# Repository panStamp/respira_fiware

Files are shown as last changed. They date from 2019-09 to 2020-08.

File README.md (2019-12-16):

# Open FIWARE air monitoring platform for urban applications

RESPIRA FIWARE is an open source air monitoring device created to sense temperature, humidity, particle matter and NO2 levels in the air. This device transmits levels and concentrations to a central FIWARE platform and has been originally created to connect and transmit against the RESPIRA Environmental IoT platform of Badajoz. Both projects have been developped by [panStamp](http://www.panstamp.com) and sponsored by [Diputación de Badajoz](https://www.dip-badajoz.es/) and [Telefónica](https://www.telefonica.com/en/)

# Index of contents

- [Introduction](docs/en/INTRODUCTION.md)
- [RESPIRA station](docs/en/RESPIRA_STATION.md)
  - [How to build RESPIRA station](docs/en/HOWTO_BUILD_STATION.md)
  - [Maintenance and calibration of RESPIRA stations](docs/en/RESPIRA_CALIBRATION.md)
  - [RESPIRA calibration tool](docs/en/RESPIRA_TOOL.md)
- [RESPIRA environmental IoT platform](docs/en/RESPIRA_PLATFORM.md)
  - [How to use the RESPIRA IoT platform](docs/en/HOWTO_RESPIRA_PLATFORM.md)
  - [Alert panel](docs/en/ALERT_PANEL.md)
  - [HTTP API](docs/en/API_DOC.md)

# Source code and documentation

The source code of the RESPIRA station and all the necessary documentation for the building and start up processes are available on [Github](https://github.com/panStamp/respira_fiware).

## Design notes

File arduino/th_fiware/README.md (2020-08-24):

# Basic FIWARE temperature and humidity sensor

This is a basic example showing how to connect a temperature and humidity sensor to our RESPIRA open platform via FIWARE UltraLight. The source code is ready to upload to a ESP8266 SoC from an Arduino IDE. The sensor is a SI7021 dual temperature and humidity sensor supporting I2C communications.

## Necessary steps before compiling:

1. Install ESP8266 Arduino cores from the Arduino boards manager by following this guide: 
https://github.com/esp8266/Arduino#installing-with-boards-manager

2. Install SparkFun's SI7021 library from the Arduino library manager:
https://github.com/sparkfun/SparkFun_Si701_Breakout_Arduino_Library

3. Install WiFi Manager by tzapu also from the Arduino library manager:
https://github.com/tzapu/WiFiManager#install-through-library-manager

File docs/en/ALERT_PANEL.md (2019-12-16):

[< back to index](../../README.md)

# Alert panel

The alert panel provides a simple way to define and track alerts based on any public IoT value published by the RESPIRA platform. Only registered users can create alerts and visualize them from their accounts.

## Alert creation

Alerts can be created from _Alerts->Manager alerts_ and then press on _Add new alert_. The following form will open:

<p align="center">
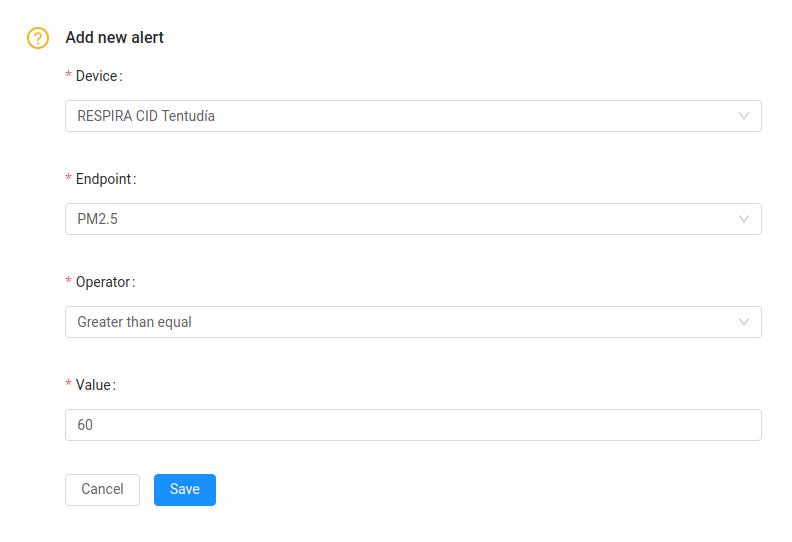
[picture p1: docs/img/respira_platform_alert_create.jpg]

</p>

This form is quite self-explanatory but the idea is to set the reading of a given device to trigger the alert whenever its value  is greater or lower (operator field) than a threshold (value field). Alerts are continuously checked and reported in the _Alert console_:

<p align="center">
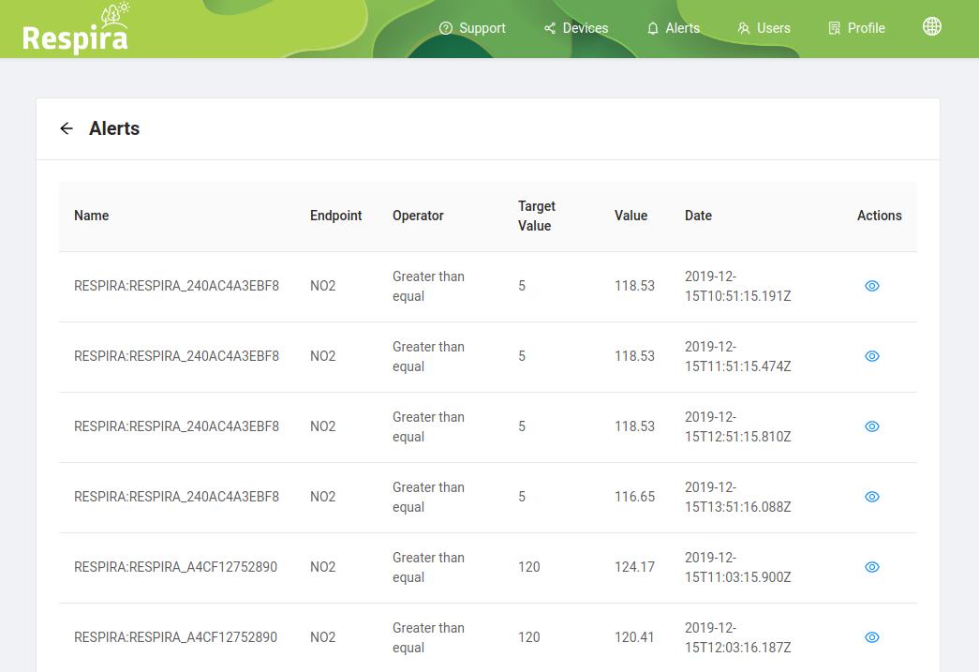
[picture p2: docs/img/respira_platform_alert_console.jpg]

</p>

At this point, the only way to navigate from the alert console to the specific device in the dashboard is to copy the id of the device from the alert console and then go to the dashboard.

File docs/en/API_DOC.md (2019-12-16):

[< back to index](../../README.md)

# HTTP API

The HTTP API provides a way for programmers and specialists to download data from specific devices in a time range. An example of this API is provided for every device on the side panel:

<p align="center">
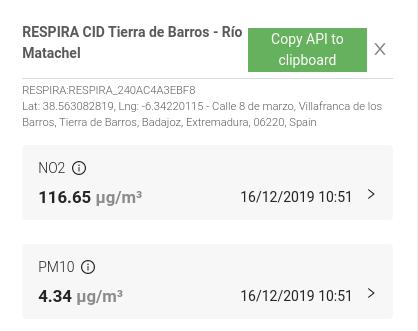
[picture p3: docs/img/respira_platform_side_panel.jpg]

</p>

Clicking on _Copy API to clipboard_ on the above panel provides the following HTTP call:

```
http://calidadmedioambiental.org/api/v1/data/RESPIRA:RESPIRA_240AC4A3EBF8/2019-12-15T10:03:41/2019-12-16T10:03:41/json
```

Then it's simply a matter of modifying the call for our date and time range. Data can be downloaded in json and csv format, according to the API format:

```
http://calidadmedioambiental.org/api/v1/data/<Device profile>:<Device id>/<initial time>/<final time>/<format>
```

Being <format> either _json_ or _csv_

Time strings need to conform to the standard format: yyyy-mm-ddTHH:MM:SS

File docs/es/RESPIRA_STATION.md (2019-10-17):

[< índice](INDEX.md)

# Índice de contenidos

- [La estación RESPIRA FIWARE](#la-estación-RESPIRA-FIWARE)
- [Especificaciones](#especificaciones)
- [Funcionamiento](#funcionamiento)
- [Componentes](#componentes)
  - [Microcontrolador](#microcontrolador)
  - [Sensores](#sensores)

# La estación RESPIRA FIWARE

La arquitectura del hardware RESPIRA es bastante sencilla. Un módulo ESP32 actúa como el cerebro de la estación medioambiental. Por otra parte, la lectura de temperatura ambiente, humedad relativa y concentraciones de NO2 y de partículas (PM) es proporcionada desde tres sensores independientes vía I2C y UART. El SoC ESP32 tiene suficiente espacio en flash y potencia para almacenar y procesar las lecturas internamente con el fin de limpiar y filtrar los datos y de ejecutar rutinas de calibración periódicas. Por último, la información procesada es transmitida a la plataforma FIWARE por medio de una [petición HTTP UltraLight 2.0](https://fiware-iotagent-ul.readthedocs.io/en/latest/usermanual/index.html).

# Especificaciones

- Parámetros proporcionados: Temperatura ambiente, humidity relativa, NO2, PM1.0, PM2.5, PM4.0, PM10, tamaño típico de partículas y [CAQI](https://en.wikipedia.org/wiki/Air_quality_index#CAQI)
- Alimentación : 5.0VDC
- Corriente máxima : 300 mA
- Comunicación : WiFi 2.4GHz
- Protocolo FIWARE: UltraLight 2.0 HTTP

# Funcionamiento

Toda estación RESPIRA recoge datos medioambientales cada 20 segundos. Estos datos son almacenados para realizar una media aritmética cada hora e inmediatamente transmitir estas medias hacia la plataforma. Las estaciones RESPIRA transmiten pues valores medios cada hora.

Por otra parte, las estaciones RESPIRA también realizan compensaciones internas de las lecturas en temperatura y también otras rutinas de compensación explicadas [aquí](RESPIRA_CALIBRATION.md).

<p align="center">
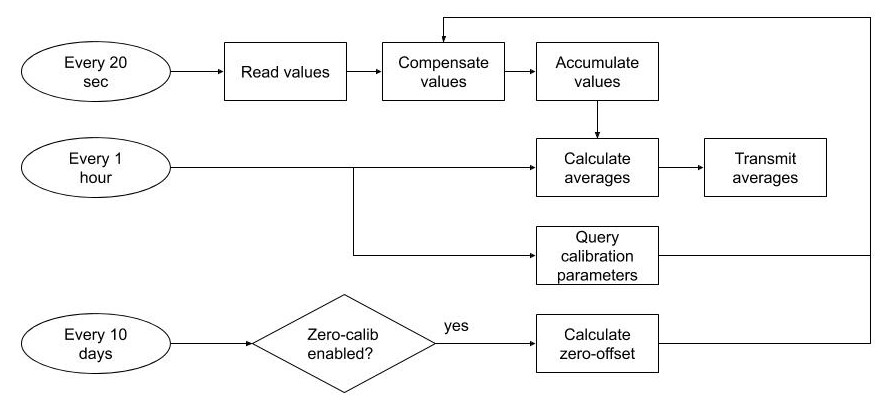
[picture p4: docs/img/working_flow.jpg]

</p>

# Componentes

RESPIRA FIWARE está formado por dos partes principales. La primera parte es la unidad microcontrolada, el cerebro de la solución que contiene el módulo ESP32 con las comunicaciones WiFi. La segunda parte es el bloque de sensorización, contenido dentro de un encapsulado con formato pagoda que garantiza la ventilación. Ambas partes comunican entre sí por medio de I2C y UART.

## Microcontrolador

Esta tarjeta usa exclusivamente componentes "con patas" (THT) con el fin de facilitar su montaje y de permitir su prototipado desde la comunidad. Es por esto que hemos escogido un módulo ESP32 en formato NodeMCU. Este módulo no sólo contiene un SoC (System On Chip) ESP32  sino que además incluye un interfaz USB, usado para programar y depurar el firmware, y de un regulador de tensión de 3.3VDC. La tarjeta NodeMCU ESP32 también incluye un par de botones que permiten poner el ESP32 en modo programación de forma manual.

<p align="center">

</p>

La tarjeta microcontrolada se ajusta a la parte izquierda de una caja FIBOX TEMPO TAM131007 para exteriores, dejando toda la parte derecha del interior de la caja para el montaje de futura sensorización así como de una fuente de alimentación de 5 VDC.

## Sensores

Los sensores quedan ensamblados en el interior de una cápsula preparada para la sensorización del aire y que facilita su ventilación de forma pasiva. Hemos elegido para este poroyecto la caja con referencia TFA-Dostmann 98.1114.02, normalmente disponible en Amazon.

RESPIRA se apoya en tres sensores externos, los cuales han sido elegidos por su respuesta, estabilidad y capacidad para comunicar de forma digital con el microcontrolador.

### Sensor de temperatura y humedad [SI7021](https://www.silabs.com/documents/public/data-sheets/Si7021-A20.pdf)

Este integrado fabricado por Silicon Labs es un sensor dual de temperatura y humedad excepcional que comunica por I2C. Existe multitud de librerías para Arduino compatibles con este sensor y también está disponible en formato de tarjeta de prototipaje, de forma que se evita el montaje superficial. Estas tarjetas con sensor SI7021 están disponibles en eBay o Aliexpress por menos de 4 EUR.

<p align="center">

</p>

### Sensor de partículas [SPS30](https://www.sensirion.com/en/environmental-sensors/particulate-matter-sensors-pm25/)

SPS30 es un sensor compacto de partículas fabricado por Sensirion. Este sensor es capaz de detectar partículas con diámetros desde 0.5 micras, calcular concentraciones para cada diámetro y también calcular la masa total por diámetro. El dispositivo SPS30 tiene dimensiones reducidas (41x41x12 mm) y dispone de conectividad por UART y por I2C. SPS30 está disponible en Mouser y en Digikey a precios que rondan los 40 EUR en pequeñas cantidades.

<p align="center">

</p>

SPS30 proporciona los siguientes parámetros:

- Concentración de PM1.0, PM2.5, PM4.0 y PM10
- Tamaño medio de las partículas detectadas

### Sensor de NO2 [ES1-NO2-50](http://pmo0ec072.pic33.websiteonline.cn/upload/ES1-NO2-50_20171212.pdf)

ES1-NO2-50 es un sensor electroquímico de NO2 sensor sensible en el rango de 0 a 50 ppm. Por supuesto, no necesitamos todo ese rango de lecturas aunque este sensor se comporta especialmente bien ante concentraciones bajas de NO2. Por otra parte, la deriva del sensor es mínima en rangos bajos de lectura y viene calibrado de fábrica. Con el fin de simplificar todavía más la integración de este sensor en nuestra estación RESPIRA, el sensor viene montado sobre una tarjeta TB600, también del mismo fabricante, que proporciona comunicación por puerto serie UART. De esta forma evitamos tener que lidiar con lecturas analógicas complicadas desde el ESP32.

<p align="center">

</p>

ES1-NO2-50 y TB600 es fabricado por ECSense y distribuído en Europa por Pewatron. Su precio ronda los 120 EUR en pequeñas cantidades.

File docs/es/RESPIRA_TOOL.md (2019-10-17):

[< índice](INDEX.md)

# Índice de contenidos

- [RESPIRA tool](#respira-tool)
- [Configuración inicial](#configuración-inicial)
- [Corrección manual por factor-offset](#corrección-manual-por-factor-offset)
- [Corrección automática por nivel cero](#corrección-automática-por-nivel-cero)
- [Reset de los parámetros de calibración](#reset-de-los-parámetros-de-calibración)
- [Lectura de los parámetros de calibración](#lectura-de-los-parámetros-de-calibración)

# RESPIRA tool

RESPIRA tool es un programa en línea de comandos (terminal) desarrollado en Python 3.7 para enviar configuración y parámetros de calibración a cualquier estación remota RESPIRA por medio de FIWARE. Ya explicamos en [esta otra sección](RESPIRA_CALIBRATION.md) dos estrategias distintas de calibración: corrección manual por factor-offset y calibración automática por nivel cero. Los siguientes apartados emplean cada uno de estos métodos por medio del correspondiente comando.

# Configuración inicial

Antes de usar RESPIRA tool necesitamos introducir nuestro service path FIWARE. A todo usuario de la plataforma RESPIRA IoT medioambiental se el proporciona un service path, una región específica dentro del Context-Broker FIWARE donde confluyen todas la sinformaciones IoT. Los usuarios pueden encontrar su service path bajo su perfil en la plataforma.

Con el service path en mano, basta con ejecutar el siguiente comando:

```
python3 respira_tool.py --set-service-path /my_service_path
```

Este comando almacena el service path en un fichero de configuración, de modo que no necesitaremos volver a ejecutar el comando salvo que que queramos cambiar a un service path distinto (distinto usuario). Podemos comprobar el service path vigente en todo momento mediante este otro comando:

```
python3 respira_tool.py --show-service-path
```

devolviendo el service path actualmente en curso:

```
/my_service_path
```

# Corrección manual por factor-offset

Asumiendo que ya se dispone de los parámetros de corrección (factor y offset), su transmisión a FIWARE sólo requiere de la ejecución de este comando:

```
python3 respira_tool.py --calibrate no2 -d RESPIRA_XXXXXXXXXXXX -f 1.0021 -o -12.687
```

Donde no2 es la lectura que deseamos corregir, RESPIRA_XXXXXXXXXXXX es el ID de la estación RESPIRA, 1.0021 el factor de corrección (o ganancia) y -12.687 es el offset de corrección. Los contaminantes soportados por esta versión del software son: no2, pm1.0, pm2.5, pm4.0 y pm10, de forma que podemso enviar calibraciones individuales para cada uno de los gases y diámetros de partículas.

```
python3 respira_tool.py --calibrate pm2.5 -d RESPIRA_XXXXXXXXXXXX -f 1.0016 -o 5.342
```

Las estaciones RESPIRA consultan el Context-Broker FIWARE de forma periódica cada hora con el fin de obtener los parámetros de configuración. Una vez obtenidos estos parámetros, la estación empieza a aplicar las correcciones sobre las siguientes lecturas, de forma que las correcciones se hacen visibles tras la siguiente transmisión una hora más tarde.

# Corrección automática por nivel cero

Esta estrategia permite a la estación restar un offset de nivel cero a cada lectura. Este nivel cero corresponde al valor mínimo detectado en el intervalo de los últimos 10 días. Podemos habilitar esta funcionalidad tanto para el sensor de NO2 como de partículas (SPS30). Es necesario reseñar que no es posible activar este tipo de compensación únicamente para un tipo de partícula sino que hay que hacerlo para todos los diámetros a los que el dispositivo SPS30 es sensible.

Estos comandos habilitan la calibración automática por nivel cero para cada sensor:

```
python3 respira_tool.py --enable-zero-calibration no2 -d RESPIRA_XXXXXXXXXXXX
python3 respira_tool.py --enable-zero-calibration pm -d RESPIRA_XXXXXXXXXXXX
```

y lo mismo para deshabilitar la funcionalidad:

```
python3 respira_tool.py --disable-zero-calibration no2 -d RESPIRA_XXXXXXXXXXXX
python3 respira_tool.py --disable-zero-calibration pm -d RESPIRA_XXXXXXXXXXXX
```

Tal y como se indica anteriormente, estos cambios surgen efecto a partir de la siguiente transmisión, una hora más tarde.

# Reset calibration settings

Digamos que queremos volver a los parámetros de configuración por defecto:

- Calibración automática por nivel cero deshabilitada para todos los sensores.
- Factor de corrección = 1 y offset = 0 para todos los contaminantes.

Podemos ejecutar este comando para volver a los valores por defecto:

```
python3 respira_tool.py --reset-calibration -d RESPIRA_XXXXXXXXXXXX
```

# Lectura de los parámetros de calibración

La opción _--read-calibration_ permite mostrarlos valores actuales de calibración de cualquier estación RESPIRA:

```
python3 respira_tool.py --read-calibration -d RESPIRA_XXXXXXXXXXXX
```

Respuesta de FIWARE:

```
Calibration settings for device :RESPIRA:RESPIRA_807D3AF39E18
NO2 automatic zero-calibration: enabled
NO2 correction factor (gain): 1
NO2 correction offset: 0
PM sensor automatic zero-calibration: enabled
PM1.0 correction factor (gain): 1
PM1.0 correction offset: 0
PM2.5 correction factor (gain): 1
PM2.5 correction offset: 0
PM4.0 correction factor (gain): 1
PM4.0 correction offset: 0
PM10 correction factor (gain): 1
PM10 correction offset: 0
```

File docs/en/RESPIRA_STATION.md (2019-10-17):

[< back to index](../../README.md)

# Index of contents

- [The RESPIRA FIWARE station](#the-respira-fiware-station)
- [Specifications](#specifications)
- [Working flow](#working-flow)
- [Components](#components)
  - [Microcontroller unit](#microcontroller-unit)
  - [Sensors](#sensors)

# The RESPIRA FIWARE station

The RESPIRA hardware follows a simple architecture. An ESP32 SoC acts as the brain of the environmental station. Ambient temperature, relative humidity, NO2 concentration and particle matter (PM) are read from three external sensors via I2C and UART. The ESP32 has sufficient space in flash and horsepower to internally store and process readings in order to filter levels and periodically run some calibration routines. Finally, processed information is transmitted to the FIWARE platform via a [HTTP UltraLight 2.0 request](https://fiware-iotagent-ul.readthedocs.io/en/latest/usermanual/index.html).

# Specifications

- Parameters provided: Temperature, humidity, NO2, PM1.0, PM2.5, PM4.0, PM10, typical particulate size and [CAQI](https://en.wikipedia.org/wiki/Air_quality_index#CAQI)
- Power supply : 5.0VDC
- Maximum current consummed : 300 mA
- Communication : WiFi 2.4GHz
- FIWARE protocol: UltraLight 2.0 HTTP

# Working flow

RESPIRA stations read environmental values every 20 seconds. This information is stored in order to get the arithmetic mean every hour and then transmit averages to the IoT platform. RESPIRA stations transmit then average values every hour.

On the other hand, RESPIRA stations also run some internal compensation algorithms based on temperature and some other calibration methods explained [here](RESPIRA_CALIBRATION.md).

<p align="center">

</p>

# Components

RESPIRA FIWARE is formed by two main blocks. The first block is the microcontroller unit, the core of the solution containing the ESP32 board and and the necessary connectivity. The second block is the sensing element, a pagoda-style enclosure containing the environmental sensors. Both main components communicate between them via UART and I2C.

## Microcontroller unit

This board relies only on "through-hole" (THT) components in order to simplify the assembly and let the community build RESPIRA stations on basic prototyping boards. As result, we have then chosen an ESP32 NodeMCU board as the ESP32 core. This board not only contains an ESP32 SoC but also a USB interface, used to program and debug the SoC, an on-board 3.3 VDC PSU and a couple of push buttons to manually put the board in programming mode.

<p align="center">

</p>

The microcontroller board fits into a FIBOX TEMPO TAM131007 box on the left side whilst keeping the right side of the enclosure free in case the user decides to add connectivity for some additional sensors or even place a 5VDC power supply.

## Sensors

Sensors are assembled into a pagoda-style enclosure in order to achive the best passive ventilation. We have chosen for this project the TFA-Dostmann 98.1114.02 enclosure, usually available on Amazon.

RESPIRA relies on three external sensors, which have been retained for their accuracy, stability and communication capabilities.

### [SI7021](https://www.silabs.com/documents/public/data-sheets/Si7021-A20.pdf) Temperature and Humidity sensor

This IC made by Silicon Labs is an exceptional dual temperature-humidity sensor that can be operated via I2C. There are lots of Arduino libraries for this sensor and is also available in form of breakout board so that there is no need to do any surface soldering. These boards are available on eBay and Aliexpress for less than 4 EUR.

<p align="center">

</p>

### [SPS30](https://www.sensirion.com/en/environmental-sensors/particulate-matter-sensors-pm25/) Particulate Matter sensor

SPS30 is an advanced compact particulate matter sensor designed and manufactured by Sensirion. It is capable to detect particles from 0.5 to 10 microns, calculate concentration for each diameter and even calculate the total mass per diameter. SPS30 features a small package (41x41x12mm) and provides connectivity via UART and I2C. SPS30 is available on Mouser and Digikey for around 40 EUR in small quantities.

<p align="center">

</p>

The following parameters are obtained from the SPS30 sensor:

- Concentration of PM1.0, PM2.5, PM4.0 and PM10
- Total average size of particules detected

### [ES1-NO2-50](http://pmo0ec072.pic33.websiteonline.cn/upload/ES1-NO2-50_20171212.pdf) NO2 sensor

ES1-NO2-50 is an electrochemical NO2 sensor sensible in the 0 to 50 ppm range. Of course we dont need that full range but the sensor performs quite well in low concentrations of gas. Moreover, the zero drift is minimum and the sensor comes calibrated from factory. In order to simplify the integration of this tiny sensor, it can be plugged onto a TB600 board, which does all the complex analog transformations and provides a clean digital reading via UART.

<p align="center">

</p>

ES1-NO2-50 and TB600 are manufactured by ECSense and can be purchased from Pewatron, the official distributor of ECSense in Europe. Price is around 120 EUR for single quantities.

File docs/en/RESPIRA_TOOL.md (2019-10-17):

[< back to index](../../README.md)

# Index of contents

- [RESPIRA tool](#respira-tool)
- [Initial configuration](#initial-configuration)
- [Manual factor-offset correction](#manual-factor-offset-correction)
- [Automatic zero-level correction](#automatic-zero-level-correction)
- [Reset calibration settings](#reset-calibration-settings)
- [Read calibration settings](#read-calibration-settings)

# RESPIRA tool

RESPIRA tool is a command-line program written in Python 3.7 to send configuration and calibration settings to remote RESPIRA stations via FIWARE. We explained in [this other section](RESPIRA_CALIBRATION.md) two different calibration strategies: manual factor-offset correction and automatic zero-calibration. The following sections will employ each of these techniques by means of the corresponding command.

# Initial configuration

Prior to using RESPIRA tool we need to enter our FIWARE service path. Every user of the RESPIRA IoT platform is given a FIWARE service path, a specific region in the FIWARE Context-Broker where all the IoT information is stored. Users can find their FIWARE service path in the profile section.

Once you get your service path simply run this command:

```
python3 respira_tool.py --set-service-path /my_service_path
```

The above command will store the service path in a configuration file so we will not need to run the command again unless we want to switch to a different FIWARE service path (a different user). We can then check the current service path with this other command:

```
python3 respira_tool.py --show-service-path
```

Which will reply with the FIWARE service path currently configured:

```
/my_service_path
```

# Manual factor-offset correction

Assuming that you already calculated your correction values (factor and offset), transmitting them to FIWARE only requires this command:

```
python3 respira_tool.py --calibrate no2 -d RESPIRA_XXXXXXXXXXXX -f 1.0021 -o -12.687
```

Where no2 is the reading to be corrected, RESPIRA_XXXXXXXXXXXX is the ID of the RESPIRA station, 1.0021 is the correction factor (or gain) and -12.687 is the correction offset. Supported pollutant by this version are: no2, pm1.0, pm2.5, pm4.0 and pm10 so we can send calibration settings for each individual gas or particulate matter.

```
python3 respira_tool.py --calibrate pm2.5 -d RESPIRA_XXXXXXXXXXXX -f 1.0016 -o 5.342
```

RESPIRA stations periodically query the FIWARE Context-Broker for new config settings every hour. Once the new settings have been retrieved, the station will start applying them for the next transmission, one hour later.

# Automatic zero-level correction

This strategy allows the station to subtract a zero-level offset to any reading. This zero-level corresponds to the minimum level detected in a 10-day interval. We can enable this functionality for both the NO2 sensor and the whole particulate matter sensor (SPS30). Please note that we can not enable zero-calibration only for a single particulate mater parameter.

These commands are used to enable automatic zero-calibration for each sensor:

```
python3 respira_tool.py --enable-zero-calibration no2 -d RESPIRA_XXXXXXXXXXXX
python3 respira_tool.py --enable-zero-calibration pm -d RESPIRA_XXXXXXXXXXXX
```

or diasble zero calibration:

```
python3 respira_tool.py --disable-zero-calibration no2 -d RESPIRA_XXXXXXXXXXXX
python3 respira_tool.py --disable-zero-calibration pm -d RESPIRA_XXXXXXXXXXXX
```

As stated before, these changes take effect starting from the next transmission, one hour later.

# Reset calibration settings

Let's say that we want to revert to the default configuration values, which are:

- Automatic zero calibration disabled for both sensors
- Manual correction factor = 1 and offset = 0 for all pollutants.

We can run the following command to set the configuration to factory defaults:

```
python3 respira_tool.py --reset-calibration -d RESPIRA_XXXXXXXXXXXX
```

# Read calibration settings

In order to show the current calibration settings from a RESPIRA station, we can use the _--read-calibration_ option:

```
python3 respira_tool.py --read-calibration -d RESPIRA_XXXXXXXXXXXX
```

Reply from FIWARE:

```
Calibration settings for device :RESPIRA:RESPIRA_807D3AF39E18
NO2 automatic zero-calibration: enabled
NO2 correction factor (gain): 1
NO2 correction offset: 0
PM sensor automatic zero-calibration: enabled
PM1.0 correction factor (gain): 1
PM1.0 correction offset: 0
PM2.5 correction factor (gain): 1
PM2.5 correction offset: 0
PM4.0 correction factor (gain): 1
PM4.0 correction offset: 0
PM10 correction factor (gain): 1
PM10 correction offset: 0
```

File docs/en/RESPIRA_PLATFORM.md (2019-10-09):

[< back to index](../../README.md)

# RESPIRA environmental IoT platform

RESPIRA is the Open IoT platform created for the Spanish Province of Badajoz to host any kind of environmental-related IoT information, including readings comming from [RESPIRA stations](RESPIRA_STATION.md), official [AEMET](http://www.aemet.es/en/portada) stations and the air quality stations coordinated by the [European Environment Agency](https://www.eea.europa.eu/).

Anyone from the community can upload relevant information about the environment in our region or transmit IoT information to the platform from commercial or DIY sensing devices. The aim of this project is then:

- Provide a creative tool for Badajoz to upload, share and manage useful environmental IoT information.
- Public deployment of low-cost IoT devices for air and water monitoring purposes.
- Creation of a dynamic community of users interested in the IoT and the environment
- Promote the green culture in Badajoz
- Showcase [FIWARE](https://www.fiware.org/) and the Open Source culture as a way to build useful solutions for the cities.

The RESPIRA platform is entirely powered by FIWARE. Communication from IoT devices to the platform is done via [UltraLight 2.0 HTTP]((https://fiware-iotagent-ul.readthedocs.io/en/latest/usermanual/index.html)). UltraLight is a lightweight IoT protocol specially created for constrained IoT hardware platforms such as Arduinos, ESP8266 and other low-power microcontrollers.

[This guide](HOWTO_RESPIRA_PLATFORM.md) shows how to use _RESPIRA environmental IoT platform_ and start sending data from your IoT device.

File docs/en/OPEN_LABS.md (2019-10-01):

[< back to index](../../README.md)

# Environmental Open Labs

Environmental Open Labs is the Open IoT platform created for the Spanish Province of Badajoz to host any kind of environmental-related IoT information, including readings comming from [RESPIRA stations](RESPIRA_STATION.md), official [AEMET](http://www.aemet.es/en/portada) stations and the [Copernicus Athmospheric Monitoring Service](https://atmosphere.copernicus.eu/).

Anyone from the community can upload relevant information about the environment in our region or transmit IoT information to the platform from commercial or DIY sensing devices. The aim of this project is then:

- Provide a creative tool for Badajoz to upload, share and manage useful environmental IoT information.
- Public deployment of low-cost IoT devices for air and water monitoring purposes.
- Creation of a dynamic community of users interested in the IoT and the environment
- Promote the green culture in Badajoz
- Showcase [FIWARE](https://www.fiware.org/) and the Open Source culture as a way to build useful solutions for the cities.

Environmental Open Labs is entirely powered by FIWARE. Communication from IoT devices to the platform is done via [UltraLight 2.0 HTTP]((https://fiware-iotagent-ul.readthedocs.io/en/latest/usermanual/index.html)). UltraLight is a lightweight IoT protocol specially created for constrained IoT hardware platforms such as Arduinos, ESP8266 and other low-power microcontrollers.

[This guide](HOWTO_OPEN_LABS.md) shows how to use _Environmental Open Labs_ and start sending data from your IoT device.

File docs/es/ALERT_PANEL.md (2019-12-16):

[< índice](INDEX.md)

# Panel de alertas

El panel de alertas proporciona una manera sencilla de crear y visualizar alertas en base a valores IoT de la plataforma RESPIRA. Sólo usuarios registrados pueden crear alertas y consultarlas desde sus respectivas cuentas.

## Alert creation

Creamos nuevas alertas desde _Alertas->Gestionar alertas_ y luego pulsamos sobre el botón _Añadir nueva alerta_. El siguiente formulario debe aparecer:

<p align="center">

</p>

El formulario es suficientemente autoexplicativo pero la idea básica es la de seleccionar una lectura de un dispositivo específico y progrmaar la alerta para que se dispare cuando esta lectura sobrepasa o desciende (campo operador) de un determinado valor límite (campo valor). Las alertas son continuamente evaluadas y reportadas en la _Consola de alertas_:

<p align="center">

</p>

Llegados a este punto, para visualizar el dispositivo en el dashboard principal tenemos que copiar el id del dispositivo desde la consola de alertas y realizar la búsqueda en el dashboard.

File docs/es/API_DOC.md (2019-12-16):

[< índice](INDEX.md)

# API HTTP

La API HTTP ofrece a programadores y especialistas una manera de descargar datos de dispositivos específicos dentro del rango de fechas y horas deseado. Desde el panel lateral de cada dispositivo podemos encontrar un ejemplo de llamada a la API:

<p align="center">

</p>

En concreto y para este dispositivo encontramos la siguiente llamada la hacer click sobre el botón _Copiar API URL_:

```
http://calidadmedioambiental.org/api/v1/data/RESPIRA:RESPIRA_240AC4A3EBF8/2019-12-15T10:03:41/2019-12-16T10:03:41/json
```

Para personalizar la llamada basta con cambiar algunos de los campos de ésta, de acuerdo con el siguiente formato de llamada:

```
http://calidadmedioambiental.org/api/v1/data/<Device profile>:<Device id>/<initial time>/<final time>/<format>
```

Siendo <format> bien _json_ o _csv_, marcando así el formato de descarga de los datos.

El formato de las fechas debe seguir el siguiente estándar: yyyy-mm-ddTHH:MM:SS

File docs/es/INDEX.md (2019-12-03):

# Plataforma abierta FIWARE para la monitorización de la calidad del aire en entornos urbanos

RESPIRA FIWARE es un dispositivo abierto IoT diseñado para monitorizar temperatura ambiente, humedad relativa y concentraciones de NO2 y de partículas en exteriores. Este dispositivo transmite niveles y concentraciones a una plataforma FIWARE central. Esta plataforma central es en su origen nuestro ecosistema _RESPIRA IoT medioambiental_ desplegado para la provincia de Badajoz. Ambos proyectos han sido desarrollados por [panStamp](http://www.panstamp.com) y esponsorizados por la [Diputación de Badajoz](https://www.dip-badajoz.es/) y [Telefónica](https://www.telefonica.com/en/) en el marco del Reto FIWARE IoT 2019.

# Index of contents

- [Introducción](INTRODUCTION.md)
- [Estación RESPIRA](RESPIRA_STATION.md)
  - [Cómo construir una estación RESPIRA](HOWTO_BUILD_STATION.md)
  - [Mantenimiento y calibración de la estación RESPIRA](RESPIRA_CALIBRATION.md)
  - [Herramienta de calibración RESPIRA](RESPIRA_TOOL.md)
- [Plataforma IoT medioambiental RESPIRA](RESPIRA_PLATFORM.md)
  - [Guía de uso de la plataforma IoT RESPIRA](HOWTO_RESPIRA_PLATFORM.md)
  - [Panel de alertas](ALERT_PANEL.md)
  - [API HTTP](API_DOC.md)

# Código fuente y documentación

El código fuente de la estación RESPIRA así como toda la documentación necesaria para su construcción y puesta en marcha están disponibles en [Github](https://github.com/panStamp/respira_fiware).

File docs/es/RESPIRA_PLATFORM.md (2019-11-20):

[< índice](INDEX.md)

# Plataforma RESPIRA IoT medioambiental

RESPIRA es también el nombre de la plataforma IoT medioambiental creada para la provincia española de Badajoz también en el marco del Reto FIWARE IoT 2019. Esta plataforma está preparada para recibir cualquier dato IoT relacionado con el medioambiente, incluyendo aquellos procedentes de las [estaciones RESPIRA](RESPIRA_STATION.md), estaciones oficiales [AEMET](http://www.aemet.es/en/portada) y las estaciones de calidad del aire coordinadas desde la  [Agencia Europea del Medioambiente](https://www.eea.europa.eu/).

Cualquier persona de la comunidad puede transmitir informaciones medioambientales de su región, tanto procedentes de fuentes oficiales como de dispositivos IoT. El propósito de este proyecto es pues:

- Proporcionar una herramienta que fomente la creatividad y la compartición de datos IoT medioambientales en la provincia de Badajoz.
- Desplegar a nivel público una red de dispositivos de bajo coste para la medición de contaminantes tanto del aire como del agua.
- Creación de una comunidad dinámica de usuarios interesados en el IoT y la preservación del medioambiente.
- Promover la cultura ecológica en Badajoz
- Promover [FIWARE](https://www.fiware.org/) y la cultura _Open Source_ como medios eficaces para el desarrollo y despliegue de soluciones Smart City.

La plataforma IoT medioambiental RESPIRA está enteramente basada en FIWARE. La comunicación con los dispositivos y servicios IoT se realiza por medio de [UltraLight 2.0 HTTP]((https://fiware-iotagent-ul.readthedocs.io/en/latest/usermanual/index.html)). UltraLight es un protocolo IoT ligero especialmente creado para la transmisión de datos IoT desde plataformas hardware con recursos reducidos, tales como Arduinos, ESP8266 y otras plataformas microcontroladas de baja potencia.

[Esta guía](HOWTO_RESPIRA_PLATFORM.md) muestra cómo usar la _plataforma IoT medioambiental RESPIRA_ y así empezar a transmitir datos IoT desde su dispositivo.

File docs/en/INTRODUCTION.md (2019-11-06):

[< back to index](../../README.md)

<p align="center">
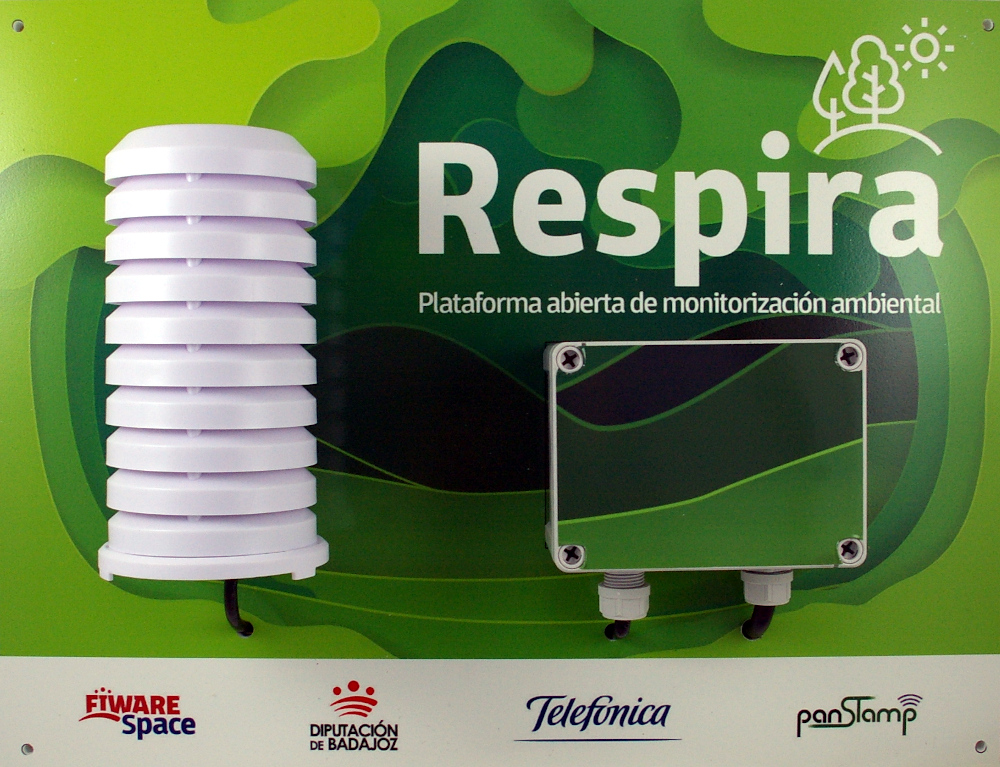
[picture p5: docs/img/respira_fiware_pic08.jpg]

</p>

# The challenge

RESPIRA FIWARE is an open source air monitoring device for urban applications. It is an evolution from precedent versions of RESPIRA designed by the company [panStamp](http://www.panstamp.com) and being deployed by the community since 2013. This version of RESPIRA has been created under the scope of the FIWARE IoT challenge 2019 launched by [Diputación de Badajoz](https://www.dip-badajoz.es/) and [Telefónica](https://www.telefonica.com/en/) by means of [FIWARE Space](https://www.fiware.space/).

# FIWARE

FIWARE is an international standard created to become the core of interoperable IoT (Internet Of Things) platforms. It is based on popular technologies such as HTTP and MongoDB and relies on a well defined M2M architecture where the Orion Context Broker, the central piece of this architecture, handles information from many different heterogeneous IoT systems.

FIWARE has been deployed in many Smart City projects around the world and is compatible with dozens of IoT technologies and data management platforms. RESPIRA FIWARE is able to transmit air pollution levels to any FIWARE-powered platform via an [HTTP UltraLight IoT agent](https://fiware-iotagent-ul.readthedocs.io/en/latest/usermanual/index.html).

Please refer to the official [FIWARE web page](https://www.fiware.org/) for more information about this technology.

# RESPIRA station

RESPIRA stations follows a very simple concept. The core, an ESP32 SoC, reads temperature, humidity, particle matter and NO2 levels periodically from three different sensors. Readings are then stored and processed locally in the MCU and finally transmitted to a FIWARE platform. The default settings make the RESPIRA station transmit to the _RESPIRA Environmental IoT platform_ but developers can change these settings to point to a different FIWARE platform.

This project contains all the necessary source code and instructions to build and deploy new RESPIRA stations. Go to [this guiding page](RESPIRA_STATION.md) for more details about how the RESPIRA hardware works and how to build your own station.

# RESPIRA environmental IoT platform

_RESPIRA environmental IoT platform_ is another open initiative of [Diputación de Badajoz](https://www.dip-badajoz.es/) and [Telefónica](https://www.telefonica.com/en/) based on FIWARE to collect, display and exploit data from many different environmental IoT sources in the Spanish province of Badajoz. This on-line platform has also been developped by [panStamp](http://www.panstamp.com) and is part of the FIWARE IoT challenge 2019 won by the company.

Open [this page](RESPIRA_PLATFORM.md) to know more about this platform.

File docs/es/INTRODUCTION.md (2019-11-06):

[< índice](INDEX.md)

<p align="center">

</p>

# El reto

RESPIRA FIWARE es un dispositivo de medición de la calidad del aire diseñado para aplicaciones urbanas. Se trata de una evolución de versiones precedentes de RESPIRA, diseño llevado a cabo por la compañía [panStamp](http://www.panstamp.com) y en despliegue por parte de la comunidad desde el año 2013. Esta versión de RESPIRA ha sido creada en el marco del reto FIWARE IoT 2019 lanzado por la [Diputación de Badajoz](https://www.dip-badajoz.es/) y [Telefónica](https://www.telefonica.com/en/) por medio de [FIWARE Space](https://www.fiware.space/).

# FIWARE

FIWARE es un estándar internacional creado para convertirse en el núcleo de cualquier solución IoT y así asegurar interoperabilidad entre plataformas IoT. Está basado en tecnologías tan populares como HTTP y MongoDB y se apoya en una arquitectura M2M bien definida, donde el Orion Context Broker, la pieza central dentro de esta arquitectura, gestiona informaciones provenientes de múltiples sistemas IoT heterogéneos.

FIWARE ha sido desplegado en multitud de proyectos Smart City por todo el mundo y es compatible con docenas de tecnologías IoT y plataformas de gestión y análisis de datos. RESPIRA FIWARE es capaz de transmitir niveles de contaminación del aire a cualquier plataforma FIWARE por medio de un [agente HTTP UltraLight](https://fiware-iotagent-ul.readthedocs.io/en/latest/usermanual/index.html).

Por favor, visite la [página oficial FIWARE](https://www.fiware.org/) para obtener más información acerca de esta tecnología.

# Estación RESPIRA

La composición de las estaciones RESPIRA es sencilla. El núcleo, un SoC ESP32, lee periodicamente temperatura, humedad, concentraciones de partículas y de NO2 de tres sensores distintos. Las lecturas son entonces almacenadas y procesadas en por el microcontrolador antes de ser transmitidas hacia la plataforma FIWARE. La configuración por defecto dentro de la programación del dispositivo RESPIRA está diseñada para transmitir contra la _plataforma IoT medioambiental RESPIRA_ aunque usuarios y desarrolladores pueden apuntar hacia cualquier otra plataforma compatible con FIWARE.

Este proyecto consta de todas las fuentes e instrucciones necesarias para construir, programar y desplegar estaciones RESPIRA. Pueden visitar [esta página](RESPIRA_STATION.md) para saber más acerca de la composición y funcionamiento del hardware RESPIRA y de cómo construir su propia estación.

# Plataforma IoT medioambiental RESPIRA

La _Plataforma IoT medioambiental RESPIRA_ es otra iniciativa abierta de [Diputación de Badajoz](https://www.dip-badajoz.es/) y de [Telefónica](https://www.telefonica.com/en/) basada en FIWARE y creada para recoger, representar y explotar datos provenientes de distintas fuentes de datos IoT mediambientales dentro de la provincia española de Badajoz. Esta plataforma on-line ha sido también desarrollada por la empresa [panStamp](http://www.panstamp.com) y forma parte del reto FIWARE IoT 2019 ganado por la compañía.

Visite [esta página](RESPIRA_PLATFORM.md) par saber más acerca de esta plataforma.

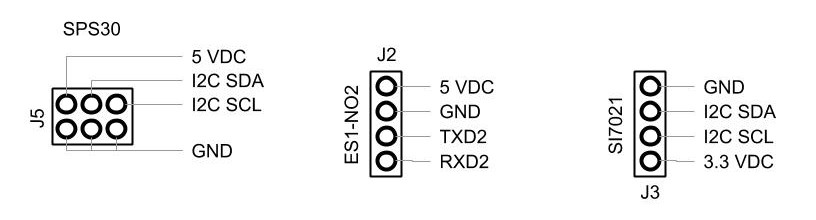
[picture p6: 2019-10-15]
docs/img/sensor_board_pinout.jpg

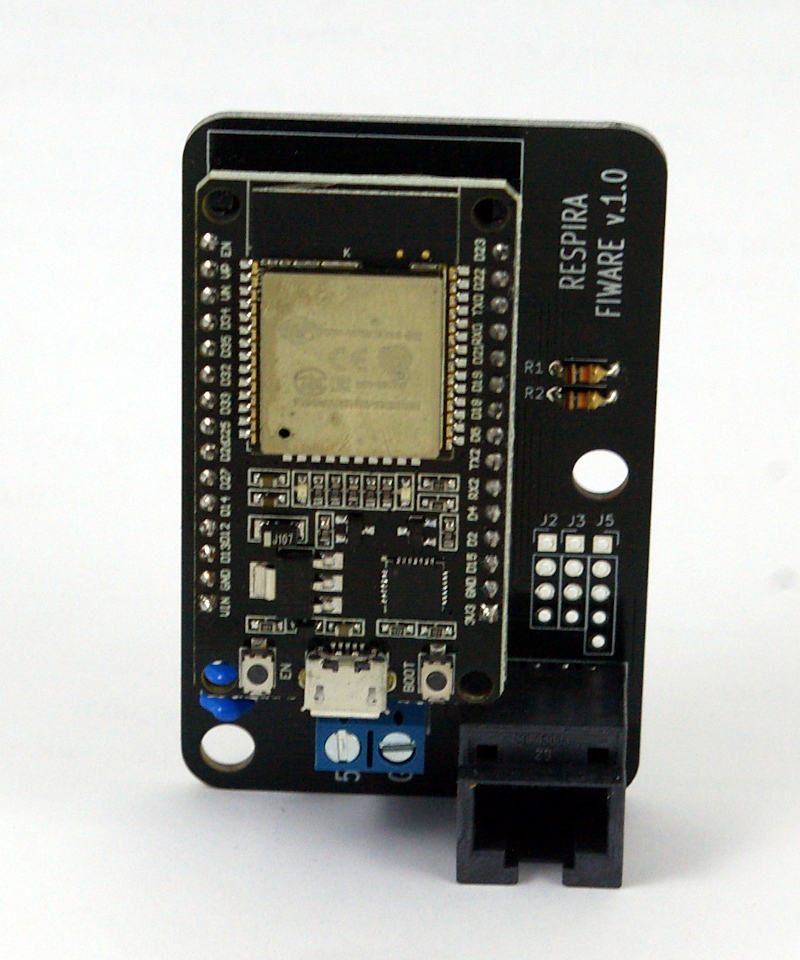
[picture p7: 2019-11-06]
docs/img/respira_fiware_pic01.jpg

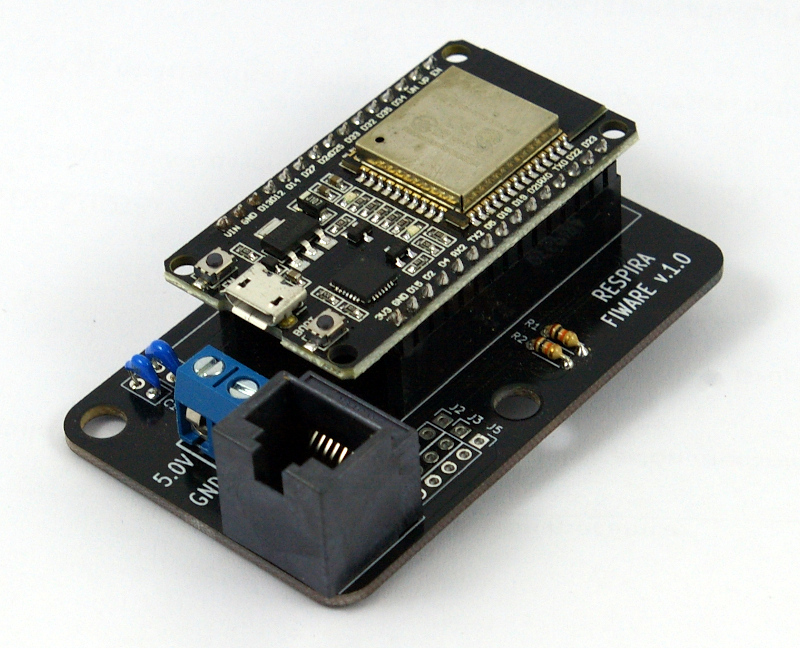
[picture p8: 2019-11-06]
docs/img/respira_fiware_pic02.jpg

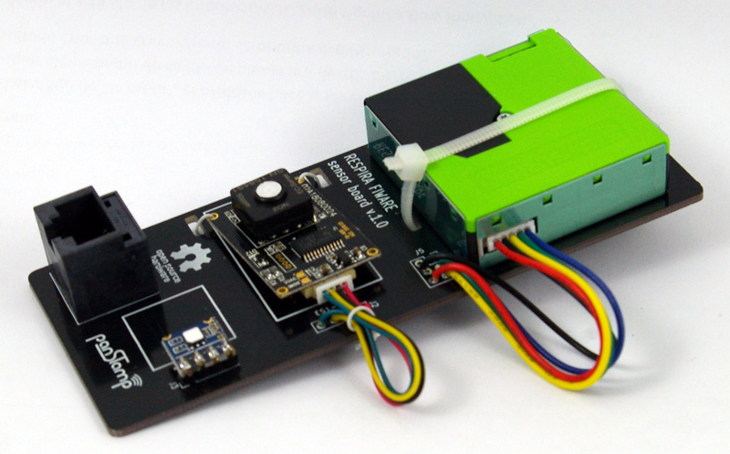
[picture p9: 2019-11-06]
docs/img/respira_fiware_pic04.jpg

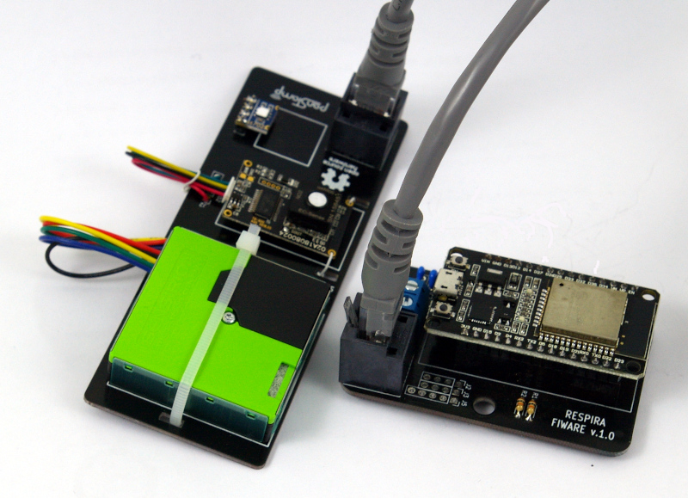
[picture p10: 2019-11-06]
docs/img/respira_fiware_pic05.jpg

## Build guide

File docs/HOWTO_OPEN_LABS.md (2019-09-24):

[< back to index](../README.md)

# Index of contents

- [Create account](#create-account)
- [Create device profile](#create-device-profile)
- [Create device](#create-device)

# Create account

Although _Environmental Open Labs_ can be freely viewed and browsed without the need to be registered, registered accounts can also create devices and transmit IoT data to the platform. If you got to this tutorial is probably because you want to connect your IoT device to _Environmental Open Labs_. In this case, please proceed to create an account from [here]().

Once your account is created

# Create device profile

Device profiles are types of devices with a documented set of endpoints (inputs). When you create a new device you need to associate it to a specific device profile. Thus, before creating your first device you have to define how many endpoints this device will have and how they will perform.

Let's say we want to create a device capable to transmit temperatures and humidities to the platform. We have then to create a new device profile from _Devices->Create new device profile_, then create a new endpoint for the temperature sensor and document it as follows:

Then repeat the same process for the humidity sensor:

After confirmation the system will return an API key that needs to be entered in your device. This key corresponds to the FIWARE API key for the UltraLight (UL) IoT agent. The platform will also return an example of UL frame that can be used in your code:

Example of UL frame: 

```
t|25.00#h|40.00
```

that can be translated into true Arduino code as follows:

```C++
sprintf(txBuf, "t|%.2f#h|%.2f", temperature, humidity);
```

_txBuff_ will need to be transmitted as payload via HTTP post to the UL agent of _Environmental Open Labs_

# Create device

Once our first device profile is created we can create a new device. Click on _Devices->Create new device_ and select the recently created device profile.

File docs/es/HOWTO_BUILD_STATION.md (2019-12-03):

[< índice](../../README.md)

# Índice de contenidos

- [Cómo montar su propia estación RESPIRA](#cómo-montar-su-propia-estación-respira)
- [Lista de materiales](#lista-de-materiales)
- [Ensamblaje](#ensamblaje)
- [Programación](#programación)
- [Conexión a una red WiFi](#conexión-a-una-red-wifi)
- [Conexión a la plataforma RESPIRA](#conexión-a-la-plataforma-respira)
- [Mantenimiento y calibración](#mantenimiento-y-calibración)

# Cómo montar tu propia estación RESPIRA

Se expone a continuación la lista oficial de materiales necesaria para la construcción de una estación RESPIRA. Si no encuentra las referencias exactas puede sustituirlas por otras de similares prestaciones. Puesto que el espíritu de este proyecto es totalmente abierto (open source), se invita a los usuarios a montar estaciones de múltiples formas así como a aportar mejoras y a reemplazar sensores por nuevas referencias.

# Lista de materiales

Se invita a los usuarios a hacer sus propios circuitos impresos a partir de los ficheros gerber puestos a disposición desde el proyecto.

## Tarjeta microcontroladora

| Referencia | Descripción | Fuente |
|---|---|---|
| U1 | 30-pin ESP32 NodeMCU board | e-bay, Amazon, Aliexpress, etc. |
| R1, R2 | 10kohm 1/6 W resistor | Mouser, Farnell, DigiKey, etc. |
| C1 | 1uF 10V ceramic capacitor | Mouser, Farnell, DigiKey, etc. |
| C2 | 100nF 10V ceramic capacitor | Mouser, Farnell, DigiKey, etc. |
| J1 | 2-pos 5mm-pitch screw connector | Mouser, Farnell, DigiKey, etc. |
| J4 | Molex 95503-2881 Vertical RJ45 connector | Mouser, Farnell, DigiKey, etc. |
| Caja | FIBOX TEMPO TAM131007 | RS, Farnell, etc. |

## Tarjeta de sensorización

| Referencia | Descripción | Fuente |
|---|---|---|
| SI7021 | SI7021 dual temperature and humidity sensor | e-bay, Amazon, Aliexpress, etc. |
| SPS30 | Sensirion particulate matter sensor | Mouser, Farnell, DigiKey, etc. |
| SPS30 connector | ZH 1.5mm JST 5-pole female connector | e-bay, Mouser, Farnell, Digikey, etc. |
| ES1-NO2-50 | NO2 sensor 0-50 ppm | ECSense, Pewatron |
| Caja | TFA-Dostmann 98.1114.02 | Amazon |
| Cable ethernet | 30 cm of CAT-6 8-pole Ethernet cable | Local store |
| Cable monopolo | Coloured <=0.5mm monopole wire | Local store |

# Ensamblaje

Todos los componentes han sido seleccionados con el fin de simplificar al máximo el proceso de ensamblaje y de soldadura. De este modo, al utilizar componentes con patillas (THT) se evita cualquier tipo de soldadura superficial (SMT) de forma que cualquier aficionado que posea un soldador y estaño puede construir su propia estación en cuestión de un par de horas.

La siguiente imagen muestra la tarjeta microncotroladora totalmente ensamblada:

<p align="center">

</p>

Como se aprecia en la imagen, toda la complejidad del diseño descansa en el módulo ESP32 de desarrollo. A parte de este módulo, la placa base apenas contiene unos pocos componentes pasivos y conectores.

El proceso de ensamblaje de la tarjeta de sensorización es también bastante sencillo. Los sensores se conectan a la tarjeta base auxiliar por medio de cables. Finalmente, la tarjeta queda fijada en el interior de la caja con forma de pagoda que protege a la electrónica de la lluvia. Tarjeta de sensorización y tarjeta microcontrolada quedan unidas por medio de un cable ethernet.

<p align="center">
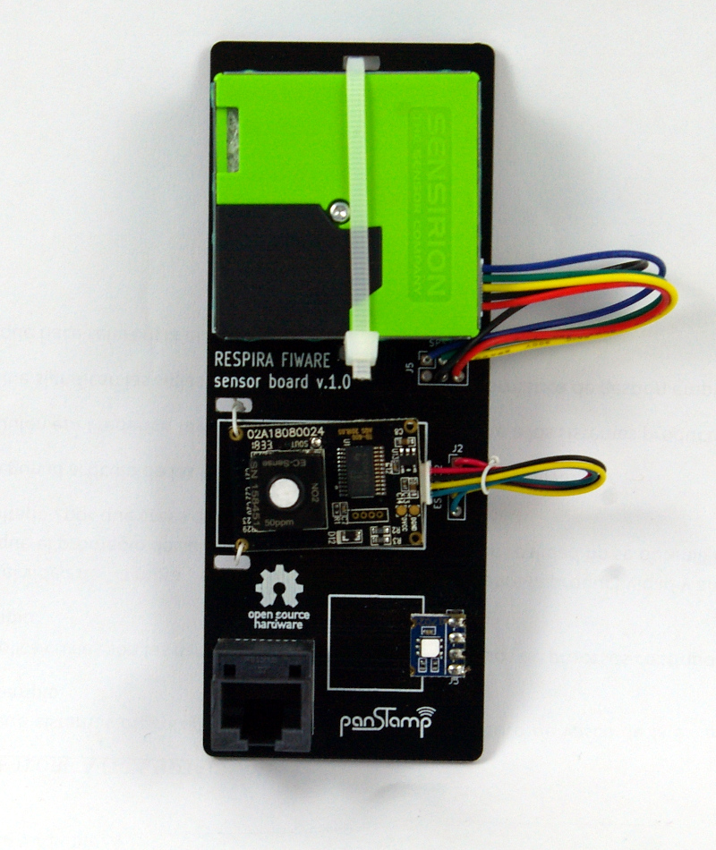
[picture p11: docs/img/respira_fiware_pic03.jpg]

</p>

Los sensores se conectan a la tarjeta siguiendo este esquema de pines

<p align="center">
<img width=5400" src="../img/sensor_board_pinout.jpg">
</p>

Se recomienda también la siguiente distribución de hilos para el cable ethernet si bien cualquier cable ethernet paralelo (el estándar) sirve para la aplicación.

<p align="center">
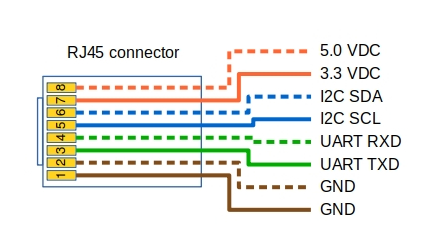
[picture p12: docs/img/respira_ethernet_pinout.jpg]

</p>

Finalmente, se muestra un par de imágenes de una estación RESPIRA completamente ensamblada. Esta estación incluye una fuente de alimentación Meanwel de 5.0VDC de forma que el dispositivo al completo puede ser alimentado desde 230VAC.

<p align="center">
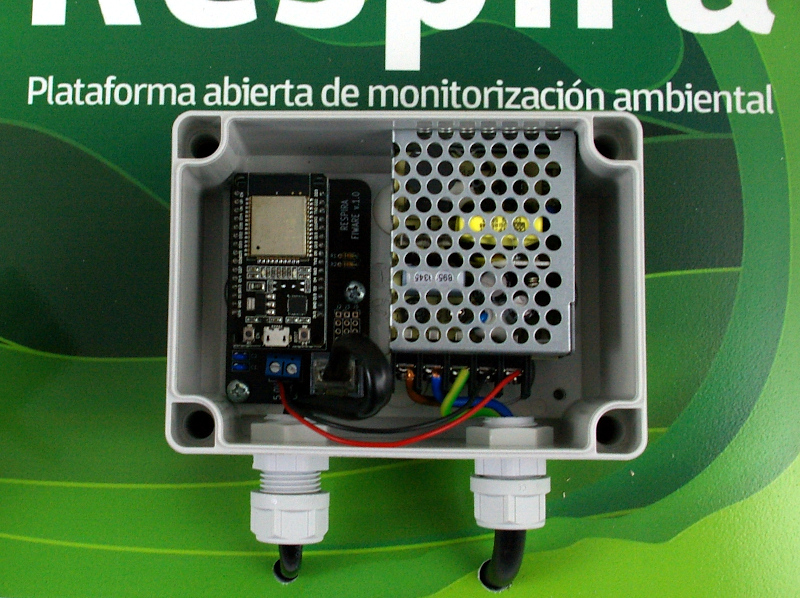
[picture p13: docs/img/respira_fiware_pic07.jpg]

</p>

<p align="center">

</p>

# Programación

El módulo ESP32 se programa desde el entorno de programación [Arduino IDE](https://www.arduino.cc/). Pero antes de intentar compilar el código, tenemos que asegurar que la siguiente lista de librerías queda instalada desde _Sketch->Include library->Manager libraries_:

- [Librería SPS30 de Paul van Haastrecht](https://github.com/paulvha/sps30). Esta librería debe ser instalada de forma manual.
- [WiFiManager para ESP32](https://github.com/zhouhan0126/WIFIMANAGER-ESP32). Esta librería debe ser instalada de forma manual.
- [Librería SI7021 de Sparkfun](https://github.com/sparkfun/SparkFun_Si701_Breakout_Arduino_Library). Esta librería puede ser instalada desde el gestor de librerrías de Arduino.
- [Librería ArduinoOTA](https://github.com/jandrassy/ArduinoOTA). Esta librería puede ser instalada desde el gestor de librerrías de Arduino.

Durante la compilación es probable que se den algunos conflictos en las librerías instaladas con respecto a los cores del ESP32. Recomendamos pues hacer un par de cambios:

Abrir el directorio que contiene las librerías de Arduino y editar sps30/sps30.h. aquí tendremos que comentar INCLUDE_SOFTWARE_SERIAL.

```C++
//#define INCLUDE_SOFTWARE_SERIAL 1
```

Tras esto debemos abrir WIFIMANAGER-ESP32/WiFiManager.h y renombrar HTTP_HEAD con un nombre distinto, como por ejemplo HTTP_HEADER:

```C++
const char HTTP_HEADER[] PROGMEM = ....
```

Y también renombrar todas las referencias a HTTP_HEAD en WIFIMANAGER-ESP32/WiFiManager.h.

Una vez finalizados estos cambios podemos por fin abrir el proyecto respira_fiware que se encuentra en el directorio arduino dentro del [repositorio](https://github.com/panStamp/respira_fiware). El código fuente ha de ser modificado con la dirección IP del servidor FIWARE, el puerto UltraLight y la API key que permite conectar la estación RESPIRA al agente IoT. Si pretende conectar la estación a nuestra plataforma IoT vaya directamente a [esta sección](#conexión-a-la-plataforma-respira)

En [respira_fiware.ino](https://github.com/panStamp/respira_fiware/blob/master/arduino/respira_fiware/respira_fiware.ino):

```C++
const char FIWARE_SERVER[] = FIWARE_SERVER_IP_ADDRESS;
const uint16_t FIWARE_PORT = FIWARE_UL_PORT;
const char FIWARE_APIKEY[] = FIWARE_UL_API_KEY;
```

Por último, debemos seleccionar _ESP32 Dev board_ en el desplegable Tools->Boards de Arduino, conectar la tarjeta ESP32 a la computadora por USB, seleccionar el puerto serie y programar la tarjeta. 

# Conexión a una red WiFi

El código integra [WiFiManager](https://github.com/tzapu/WiFiManager), una popular librería de Arduino que permite seleccionar la red WiFi a la que queremos que se conecte nuestro ESP32 por medio de una página web embebida. La primera vez que la estación RESPIRA es alimentada, ésta despliega un punto de acceso con SSID "RESPIRA_XXXXXXXXXXXX", siendo "XXXXXXXXXXXX" la dirección MAC del módulo ESP32. Este punto de acceso es también desplegado al intentar conectar a una red WiFi anterior sin éxito. Con el punto de acceso del ESP32 en marcha basta con seguir estos pasos:

1- Conectar a la red WiFi "RESPIRA_XXXXXXXXXXXX" desde un teléfono móvil.
2- Abrir la página web http://192.168.4.1. El siguiente interfaz se mostrará en pantalla:

<p align="center">

</p>

3- Pulsar sobre el botón "Configure WiFi"
4- Rellenar los campos SSID y password
5- Salvar la configuración y reiniciar la tarjeta.

# Conexión a la plataforma RESPIRA

El proceso de conexión de cualquier estación RESPIRA FIWARE a la [plataforma IoT medioambiental RESPIRA](RESPIRA_PLATFORM.md) es muy simple. Una vez registrado en la plataforma basta con visualizar los detalles del perfil de dispositivo RESPIRA ya creado en la cuenta. Dentro de estos detalles aparece el API key que debe ser incluído en la programación del dispositivo electrónico, así como la dirección IP del servidor FIWARE y el puerto UltraLight de la aplicación.

Dentro del código, tenemos que cambiar la API key y dejar el resto de parámetros en sus valores por defecto:

```C++
const char FIWARE_SERVER[] = "calidadmedioambiental.org";
const uint16_t FIWARE_PORT = 80;
const char FIWARE_APIKEY[] = FIWARE_UL_API_KEY;
```

# Mantenimiento y calibración

Las estaciones RESPIRA requiren de mantenimiento y de calibración periódicos. [Esta guía](RESPIRA_CALIBRATION.md) proporciona algunas pistas sobre cómo y dónde instalar las estaciones y de cómo mantenerlas correctamente.

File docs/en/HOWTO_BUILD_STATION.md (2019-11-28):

[< back to index](../../README.md)

# Index of contents

- [How to build your own RESPIRA FIWARE station](#how-to-build-your-own-respira-fiware-station)
- [Bills of materials](#bills-of-materials)
- [Assembly](#assembly)
- [Programming](#programming)
- [Joining a WiFi network](#joining-a-wiFi-network)
- [Connecting to RESPIRA environmental IoT platform](#connecting-to-respira-environmental-iot-platform)
- [Maintenance and calibration](#maintenance-and-calibration)

# How to build your own RESPIRA FIWARE station

The following are the official bills of materials used in this project. If you don't find the exact references of course you can use your own ones. Since the spirit of this project is totally open source, users can build this station in very different ways, add improvements and even replace the sensors by new references.

# Bills of materials

Users are invited to make their own PCB's based on the available schematics and gerbers.

## Microntroller board

| Reference | Description | Source |
|---|---|---|
| U1 | 30-pin ESP32 NodeMCU board | e-bay, Amazon, Aliexpress, etc. |
| R1, R2 | 10kohm 1/6 W resistor | Mouser, Farnell, DigiKey, etc. |
| C1 | 1uF 10V ceramic capacitor | Mouser, Farnell, DigiKey, etc. |
| C2 | 100nF 10V ceramic capacitor | Mouser, Farnell, DigiKey, etc. |
| J1 | 2-pos 5mm-pitch screw connector | Mouser, Farnell, DigiKey, etc. |
| J4 | Molex 95503-2881 Vertical RJ45 connector | Mouser, Farnell, DigiKey, etc. |
| Enclosure | FIBOX TEMPO TAM131007 | RS, Farnell, etc. |

## Sensor board

| Reference | Description | Source |
|---|---|---|
| SI7021 | SI7021 dual temperature and humidity sensor | e-bay, Amazon, Aliexpress, etc. |
| SPS30 | Sensirion particulate matter sensor | Mouser, Farnell, DigiKey, etc. |
| SPS30 connector | ZH 1.5mm JST 5-pole female connector | e-bay, Mouser, Farnell, Digikey, etc. |
| ES1-NO2-50 | NO2 sensor 0-50 ppm | ECSense, Pewatron |
| Enclosure | TFA-Dostmann 98.1114.02 | Amazon |
| Ethernet cable | 30 cm of CAT-6 8-pole Ethernet cable | Local store |
| Monopole wire | Coloured <=0.5mm monopole wire | Local store |

# Assembly

All parts have been selected to avoid any surface mount soldering (SMT). This means that anyone with a minimum experience in soldering electronic parts and owning a soldering iron should be able to assemble this station. The main microcontroller board is shown in the image below:

<p align="center">

</p>

As seen in the above picture, most of the complexity of the electronics is already included in the ESP32 development board. Apart from this main board, the MCU carrier board just needs a few passive components and connectors.

Assembling the sensor board is quite simple as well. Sensor units need to be connected to the auxiliary sensor board with wires. Finally, the sensor board is fixed into the pagoda-style enclosure and connected to the main microcontroller board by means of an Ethernet cable.

<p align="center">

</p>

Sensors need to be individually soldered to the sensor board by following this pinout:

<p align="center">
<img width=5400" src="../img/sensor_board_pinout.jpg">
</p>

The following pinout diagram is recommended for the Ethernet cable:

<p align="center">

</p>

These images show a complete RESPIRA FIWARE station assembled and connected. This station includes a Meanwel 5.0VDC power supply so that the whole electronics can be connected to AC mains:

<p align="center">

</p>

<p align="center">

</p>

# Programming

The ESP32 is programmed from the [Arduino IDE](https://www.arduino.cc/). Before trying to compile the code, the following libraries need to be installed from _Sketch->Include library->Manager libraries_:

- [Paul van Haastrecht's SPS30 library](https://github.com/paulvha/sps30). This library needs to be installed manually from the repository.
- [WiFiManager for ESP32](https://github.com/zhouhan0126/WIFIMANAGER-ESP32). This library needs to be installed manually from the repository.
- [Sparkfun's SI7021 library](https://github.com/sparkfun/SparkFun_Si701_Breakout_Arduino_Library). This library can be installed from Arduino's library manager.
- [ArduinoOTA library](https://github.com/jandrassy/ArduinoOTA). This library can be installed from Arduino's library manager.

We found some problems during compilation due to some conflicts in the libraries for the ESP32 core. These conflicts can be fixed by applying the following changes:

Go to your libraries directory and open sps30/sps30.h. Then comment out INCLUDE_SOFTWARE_SERIAL.

```C++
//#define INCLUDE_SOFTWARE_SERIAL 1
```

After this open WIFIMANAGER-ESP32/WiFiManager.h and rename HTTP_HEAD to HTTP_HEADER:

```C++
const char HTTP_HEADER[] PROGMEM = ....
```

And also rename all the references to HTTP_HEAD in WIFIMANAGER-ESP32/WiFiManager.cpp

Once the above changes have been made, we can finally open respira_fiware from the Arduino IDE. The project is in the directory named as arduino in the [project repository](https://github.com/panStamp/respira_fiware). The source code needs to be modified with the FIWARE server IP address, the UltraLight port and the correct API Key to connect your RESPIRA station to the FIWARE IoT agent. If you are connecting the station to our online platform then jump to [this section](#connecting-to-respira-environmental-iot-platform)

From [respira_fiware.ino](https://github.com/panStamp/respira_fiware/blob/master/arduino/respira_fiware/respira_fiware.ino):

```C++
const char FIWARE_SERVER[] = FIWARE_SERVER_IP_ADDRESS;
const uint16_t FIWARE_PORT = FIWARE_UL_PORT;
const char FIWARE_APIKEY[] = FIWARE_UL_API_KEY;
```

Finally, select the board _ESP32 Dev board_ from Arduino Tools->Boards, connect the ESP32 board to your computer via USB, select the right serial port and upload the code to the board. 

# Joining a WiFi network

The code integrates [WiFiManager](https://github.com/tzapu/WiFiManager), a popular Arduino library providing a simple web interface to help connect devices to existing WiFi networks. The first time a RESPIRA station is powered on, it deploys a basic WiFi access point with name "RESPIRA_XXXXXXXXXXXX", being "XXXXXXXXXXXX" the MAC address of the ESP32 module. This access point is also deployed after trying to connect to a precedent WiFi network without success. Once WiFiManager is running we need to follow these steps:

1- Connect to the "RESPIRA_XXXXXXXXXXXX" WiFi network from a cell phone
2- Open the web page http://192.168.4.1. The following interface will appear on the screen:

<p align="center">

</p>

3- Press on the "Configure WiFi" button
4- Fill SSID and password
5- Save the settings and let the hardware restart

# Connecting to RESPIRA environmental IoT platform

Connecting new RESPIRA FIWARE stations to [RESPIRA environmental IoT platform](RESPIRA_PLATFORM.md) is very simple. Once logged into your account you need to create a new device profile and select _RESPIRA FIWARE station_ from the wizard. The platform will return a new API key for this device profile which will have to be entered into the Arduino code.

Once into the Arduino code, set the API key and leave the rest of FIWARE constants unmodified:

```C++
const char FIWARE_SERVER[] = "calidadmedioambiental.org";
const uint16_t FIWARE_PORT = 80;
const char FIWARE_APIKEY[] = FIWARE_UL_API_KEY;
```

# Maintenance and calibration

RESPIRA stations need to be periodically maintained. [This guide](RESPIRA_CALIBRATION.md) provides some tips about where to install your stations and how to maintain them up to date.

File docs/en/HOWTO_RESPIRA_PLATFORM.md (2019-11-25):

[< back to index](../../README.md)

# Index of contents

- [Create account](#create-account)
- [Create device profile](#create-device-profile)
- [Create device](#create-device)

# Create account

Although _RESPIRA environmental IoT platform_ can be freely viewed and browsed without the need to be registered, registered accounts can also create devices and transmit IoT data to the platform. If you got to this tutorial is probably because you want to connect your IoT device to _RESPIRA environmental IoT platform_. In this case, please proceed to create an account from [here](http://calidadmedioambiental.org).

# Create device profile

Device profiles are types of devices with a documented set of readings (inputs or endpoints). When you create a new device you need to associate it to a specific device profile. Thus, before creating your first device you have to define how many endpoints this device will have and how they will perform.

Let's say we want to create a weather station that we want to connect to the platform. We have then to create a new device profile from _Device->Device profiles->Add device profile_ as follows:

<p align="center">
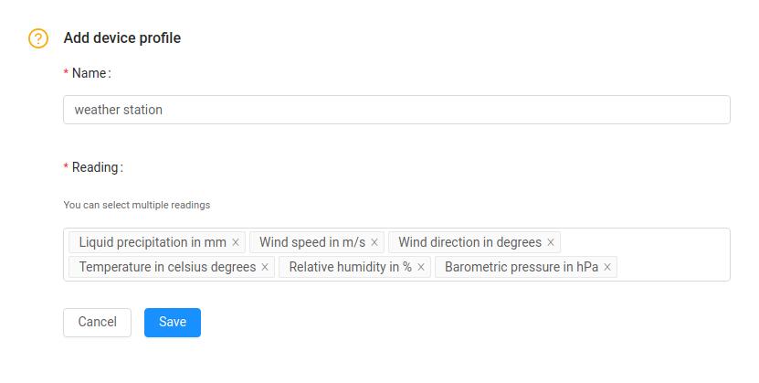
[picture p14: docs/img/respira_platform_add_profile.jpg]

</p>

Once the device profile has been created we need to take the API Key from the Device Profile list. This key corresponds to the FIWARE API key for the UltraLight (UL) IoT agent.

<p align="center">
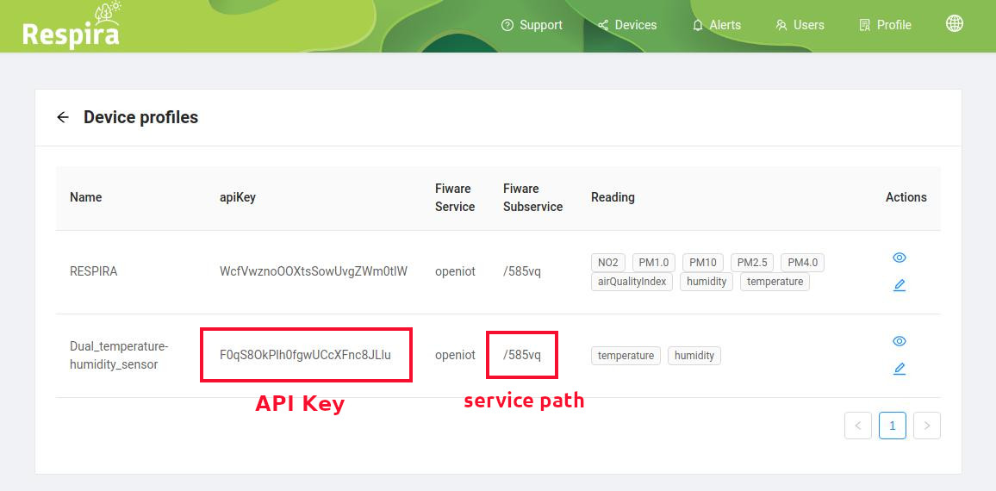
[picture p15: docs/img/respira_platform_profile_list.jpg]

</p>

By clicking on the eye icon an example of UltraLight frame is displayed. We can use this example in our source code.

<p align="center">
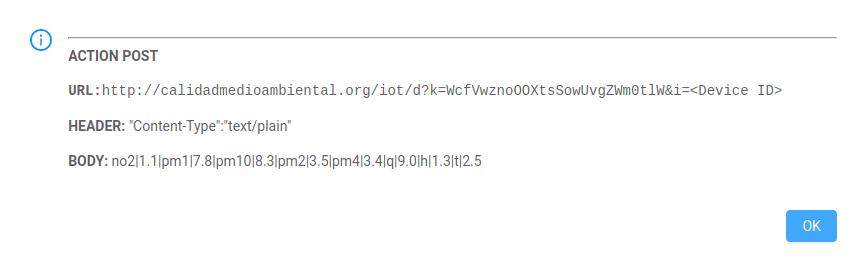
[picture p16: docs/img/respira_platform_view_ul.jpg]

</p>

The convention of the variable nomenclature needs to be followed according to the example returned by the platform. Otherwise, the platform would not be able to identify the nature of the readings received.

Example of UL frame: 

```
t|25.00#h|40.00
```
Where t means temperature and h humidity. The precedent UltraLight frame would translate into the following Arduino code:

```C++
sprintf(txBuf, "t|%.2f#h|%.2f", temperature, humidity);
```

_txBuff_ will need to be transmitted as payload via HTTP post to the UL agent of _RESPIRA environmental IoT platform_. The destination URL for the transmission is also included in the example returned by the device profile manager.

# Create device

Once our first device profile is configured we can create a new device. This tutorial does not cover the process related to the development of the embedded code. You can however use the [source code](https://github.com/panStamp/respira_fiware/tree/master/arduino/respira_fiware) of the RESPIRA station as a basis for your developments.

Devices are automatically created upon reception of the first UL frame. The UltraLight transmission needs to be done against a known API Key. Each API Key corresponds to a specific device profile so every time an UL frame is received, data is interpreted according to a specific device profile.

In order to create a new device you need to program your electronic board and transmit an UL frame with the right API key. The RESPIRA platform will then receive the UL frame and will initialize the device in the database for you. Once the device has been automatically created by the platform we can edit it with the corresponding name, description and location.

<p align="center">
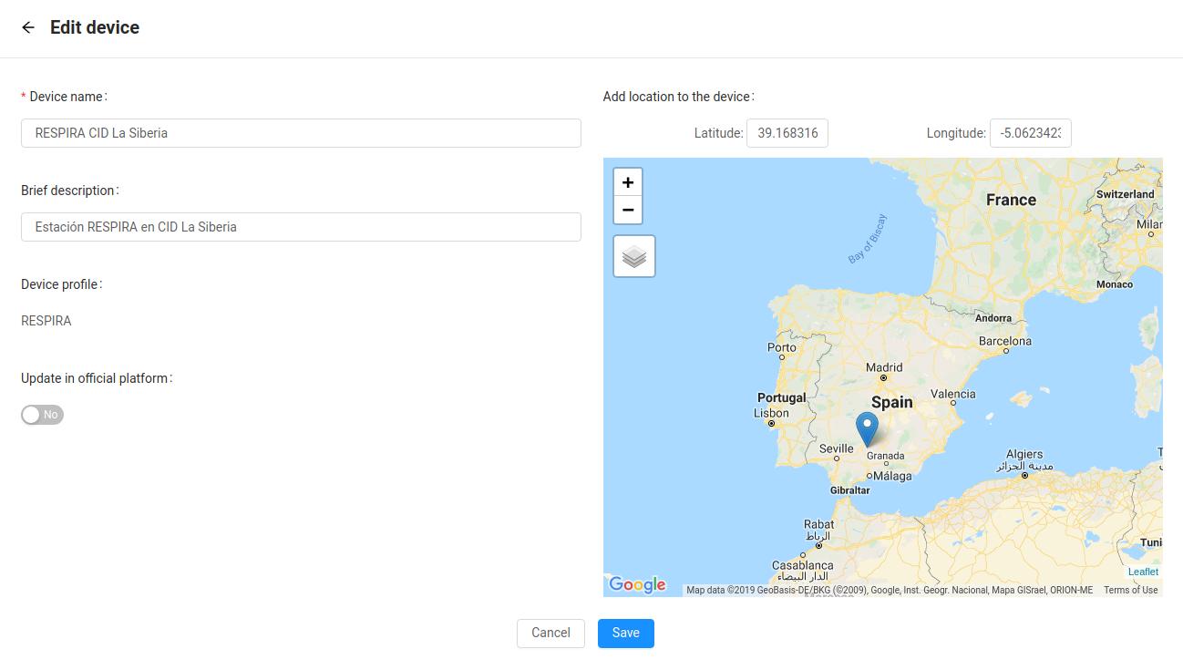
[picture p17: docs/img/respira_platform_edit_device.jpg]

</p>

It's important to add the right location for the device since this will place the device on the map.

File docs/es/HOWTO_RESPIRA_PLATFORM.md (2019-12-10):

[< índice](../../README.md)

# Índice de contenidos

- [Creación de cuenta](#creación-de-cuenta)
- [Creación de perfil de dispositivo](#creación-de-perfil-de-dispositivo)
- [Creación de dispositivos](#creación-de-dispositivos)

# Creación de cuenta

La plataforma IoT RESPIRA es de libre acceso y puede ser consultada por cualquier usuario sin necesidad de registrarse. Sin embargo, el registro sí es necesario en el caso en el que se desee crear dispositivos y darlos de alta en la aplicación. Si desea realizar ésta y otras operaciones en la plataforma le invitamos a que se registre en [este enlace](http://calidadmedioambiental.org).

# Creación de perfil de dispositivo

Los perfiles de dispositivo son estructuras de datos que contienen lecturas (entradas o endpoints). Cuando se crea un dispositivo y empieza a transmitir, éste debe venir asociado a un determinado perfil de dispositivo. De este modo, antes de poner en marcha un dispositivo se hace necesario definir un nuevo perfil de dispositivo o bien acogerse a uno de los perfiles ya disponibles. El perfil de dispositivo define el número y tipo de lecturas proporcionadas por el dispositivo.

Supongamos que queremos conectar una estación meteorológica a la plataforma. Necesitamos entonces definir un perfil de dispositivo que contenga todas y cada una de las lecturas proporcionadas por la estación. Para crear un nuevo perfil debemos acceder desde la plataforma en _Dispositivos->Perfiles de dispositivo->Añadir perfil de dispositivo_.

<p align="center">

</p>

Una vez creado el perfil de dispositivo debemos copiar la API Key disponible en el listado de perfiles. Esta clave corresponde con la API Key del agente UltraLight (UL) FIWARE.

<p align="center">

</p>

Haciendo click sobre el icono del ojo se despliega además un ejemplo de trama UltraLight que podemos usar en el código fuente de nuestra estación meteorológica. La nomenclatura UL de las variables presentado en el ejemplo devuelto por la plataforma debe ser respetado. De otro modo, la plataforma no sabría identificar la naturaleza de las lecturas.

<p align="center">

</p>

Ejemplo de trama UltraLight para un sensor de temperatura y humedad:

```
t|25.00#h|40.00
```

Donde t corresponde a la lectura de la temperatura y h a la de humedad. La trama UltraLight anterior se traduciría por ejemplo a código Arduino de la siguiente forma:

```C++
sprintf(txBuf, "t|%.2f#h|%.2f", temperature, humidity);
```

_txBuff_ sería entonces el contenido del paquete (payload) que deberá ser transmitido a la plataforma IoT vía HTTP POST. En el ejemplo devuelto por el gestor de perfiles de dispositivo se incluye asimismo la URL contra la que realizar la transmisión.

# Creación de dispositivos

Una vez creado un primer perfil de dispositivo estamos por fin en disposición de trabajar sobre nuestro dispositivo. Este tutorial no cubre todo lo relativo al desarrollo del código fuente del dispositivo. Para esto último pueden consultar el [código fuente](https://github.com/panStamp/respira_fiware/tree/master/arduino/respira_fiware) de la estación RESPIRA.

Los dispositivos son descubiertos por la plataforma y generados de forma automática en ésta tras recibir las primeras transmisiones UltraLight por parte del dispositivo. Es por esto que el dispositivo ha de transmitir con la API Key designada por la plataforma. Cada API Key corresponde a un perfil de dispositivo, de forma que cada transmisión UltraLight queda asociada a un perfil en concreto y de este modo la plataforma es capaz de decodificar la información.

Una vez nuestro dispositivo ha sido puesto en marcha y ha realizado la primera transmisión, la plataforma IoT RESPIRA dará de alta el dispositivo en el listado _Dispositivos->Mis dispositivos_. El dispositivo será identificable por su ID, que corresponde al introducido en el código fuente de la electrónica. Llegados a este punto podemos editar nuestro recién creado dispositivo desde el panel de dispositivos, otorgándole un nombre, una descripción y una ubicación que ayuden a a otros usuarios a identificar el dispositivo en la plataforma.

<p align="center">

</p>

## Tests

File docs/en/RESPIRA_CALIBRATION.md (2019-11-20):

[< back to index](../../README.md)

# Index of contents

- [Calibration of RESPIRA](#calibration-of-respira)
- [Previous tests and calculations](#previous-tests-and-calculations)
- [Correction mechanisms](#correction-mechanisms)
- [Remote calibration](#remote-calibration)

# Calibration of RESPIRA

RESPIRA, like any other environmental station, is based on sensors whose performance gets worse over time. Sensor degradation depends of course on the quality of sensors but also on temperature, moisture, presence of dirt and the concentration of pollution there where the sensor is installed. Sensors in very polluted environments typically need to be recalibrated more often than sensors in cleaner environments.

SPS30 and ES1-NO2 can be considered as low-cost sensors but both provide a decent response in terms of accuracy and drift. Of course, they can not compete against official air quality stations but they do perform nicely if you take the following suggestions into consideration:

- Install the station totally protected against direct sunlight. Electronics do not like high temperatures. Moreover, this will also avoid drastic temperature changes that might affect readings.
- Avoid highly polluted environments since sensors rapidly wear out and maintenance becomes more complicated. Environments with high concentrations of pollutants typically need to be monitored with heavy air quality stations. These stations usually need weekly or even daily maintenance.
- Protect the station against heavy wind and rain. The pagoda-style enclosure where the sensors are located can support vertical and inclined rain but not horizontal projections of water. This enclosure has not either been tested under strong wind.
- Check the output of the station against other sources over time. You can use another newer station for instance, before its final installation.
- Don't get mad for little discrepancies between stations and readings. Anything under 400 ug/m3 for the NO2 readings and 30 ug/m3 for the particulate matter sensor are perfectly acceptable.
- Check the WiFi connection before installing the station. This may save you some troubles.

# Previous tests and calculations

We can analyze the state of a sensor by comparing ideal performance against real performance. An ideal sensor would provide a nice graph where Y (real reading) = X (ideal reading) whilst a real sensor includes an offset (B) and a parasite gain (A). The following chart shows both scenarios:

<p align="center">
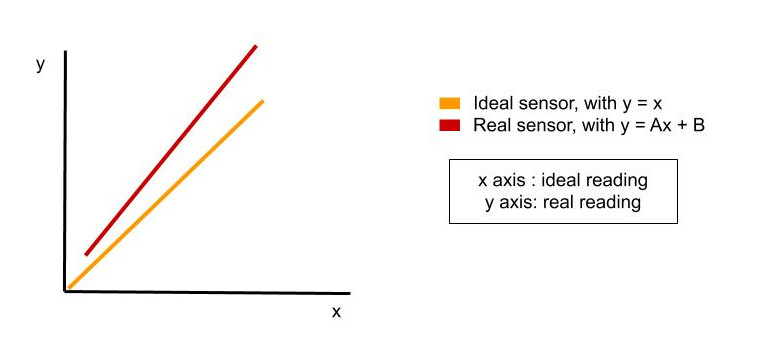
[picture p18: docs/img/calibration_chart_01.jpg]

</p>

In order to get A and B from a real sensor we would need at least two real measurement points. This can be done in a laboratory or in the field by means of external gas injectors. Longer tests can also be run in parallel against newer stations or any other calibrated equipment, as stated before. New ECS-NO2 sensors are factory calibrated and can be used to recalibrate older stations. Once A and B have been calculated we can then apply corrections in the sensor as explained later in this document.

# Correction mechanisms

The Arduino code contains two mechanisms to compensate for sensor drift. The first method relies on simple factor (gain) and offset compensation so it's a matter of applying A and B calculated in the precedent step. The code also includes an automatic zero-level calibration for both the NO2 and the particulate matter sensor. The station continuously saves the lowest value measured for every polluant within the last 10 days. Enabling this method on the station takes the minimum value as a correction offset that is then applied every 10 days. The following image shows how the minimum value registered within a period of time can be used to zero-compensate readings:

<p align="center">
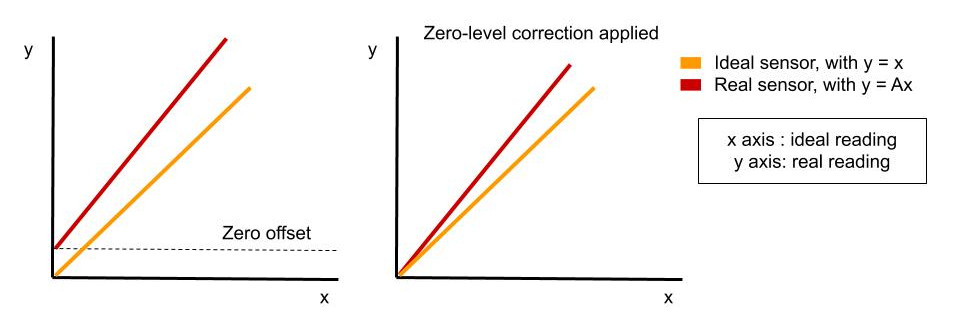
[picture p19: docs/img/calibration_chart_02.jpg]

</p>

Zero-level corrections assume that the lowest reading registered corresponds to what it should be 0 ug/m3 so please consider whether your station is eligible for this strategy before enabling it. This technique is only valid there where concentrations have proven to go down to (almost) zero at least once in 10 days. Stations installed in areas where pollution is always present and never go down to near zero should not rely on automatic zero-level calibration. Instead, manual factor-offset corrections should be periodically applied.

# Remote calibration

The RESPIRA project includes RESPIRA tool, a Python command-line program made to send calibration settings to FIWARE. RESPIRA stations request calibration information from FIWARE before transmitting pollution values. These settings are then applied starting from the next transmission, one hour later.

The following command sends calibration factor (A) = 1.0021 and offset (B) = -12.687 for the NO2 readings and the station with ID RESPIRA_XXXXXXXXXXXX:

```
python3 respira_tool.py --calibrate no2 -d RESPIRA_XXXXXXXXXXXX -f 1.0021 -o -12.687
```

[This page](RESPIRA_TOOL.md) explains all the necessary about RESPIRA tool regarding the remote configuration of stations.

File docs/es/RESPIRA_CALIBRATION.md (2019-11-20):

[< índice](INDEX.md)

# Índice de contenidos

- [Calibración de RESPIRA](#calibración-de-respira)
- [Tests y cálculos previos](#tests-y-cálculos-previos)
- [Mecanismos de corrección](#mecanismos-de-corrección)
- [Calibración remota](#calibración-remota)

# Calibración de RESPIRA

RESPIRA, como cualquier otra estación de monitorización medioambiental, está basada en sensores cuyo comportamiento empeora con el paso del tiempo. La degradación de este comportamiento depende por supuesto de la calidad del sensor pero también depende de las temperaturas soportadas, de la presencia de humedad, de suciedad y de las concentraciones de contaminantes a los que es sometido. Sensores en entornos altamente contaminados requieren de recalibración con mayor periodicidad que aquellos sensores que funcionan en entornos poco contaminados.

SPS30 y ES1-NO2 pueden ser considerados como sensores de bajo coste, si bien ambos sensores proporcionan una respuesta bastante decente en términos de precisión y de deriva. Es obvio que estos sensores no pueden competir con sensores presentes en las estaciones oficiales pero pueden llegar a ofrecer prestaciones bastante buenas siempre y cuando se respeten las siguientes recomendaciones:

- Instalar la estación protegida de la incidencia directa de los rayos del sol. Las altas temperaturas son perjudiciales para el buen funcionamiento de la electrónica y de paso evitamos los cambios bruscos de temperatura, que afectan negativamente a las lecturas de concentración de contaminantes.
- Evitar entornos con mucha contaminación puesto que los sensores pueden llegar a degradarse rápidamente y su mantenimiento se complica. Los entornos con altos niveles de contaminación necesitan de estaciones pesadas de monitorización del aire. Estas estaciones son típicamente mantenidas de forma diaria o semanal.
- Proteger las estaciones de fuertes lluvias. La caja tipo pagoda que alberga los sensores puede soportar lluvias verticales pero no proyecciones horizontales de agua. Esta caja no ha sido probada en situaciones de fuerte viento.
- Cotejar periódicamente las lecturas porporcionadas por la estación RESPIRA con otras fuentes. Puede usarse como fuente de referencia una estación RESPIRA nueva, antes de ser instalada en su ubicación final.
- No debemos sorprendernos si observamos discrepancias entre estaciones y lecturas. Diferencias que ronden los 400 ug/m3 en las lecturas de NO2 y 30 ug/m3 en las lecturas de concentración de partículas son perfectametne asumibles.
- Comprobar la conexión WiFi antes de instalar la estación. Esto nos evitará algún que otro problema.

# Tests y cálculos previos

Podemos analizar el comportamiento de un sensor al compararlo con su comportamiento ideal. Un sensor ideal ofrecería un comportamiento modelizado por una bonita línea donde Y (lectura real) = X (lectura ideal) mientras que un sensor real incluiría un offset (B) y una ganancia parásita (A). La siguiente gráfica muestra ambos escenarios:

<p align="center">

</p>

Para obtener los valores de A y B necsitamos al menos dos puntos reales de medida contrastados. Estas medidas pueden realizarse en un laboratorio o sobre el terreno por medio de inyectores de gas específicos para uso en calibración. También pueden llevarse a cabo tests de larga duración dejando instrumental calibrado o una estación RESPIRA nueva (calibrada de fábrica) junto a la estación a calibrar, tal y como se comentaba en la sección anterior.

# Mecanismos de corrección

El código Arduino incluye dos mecanismos para compensar la deriva de los sensores. El primer método se basa en la aplicación de un factor o ganancia y un offset que corrigen la lectura. En este caso basta con aplicar A y B calculados en el paso anterior. El código fuente también incluye un método de compensación automática por corrección del nivel cero de lectura. Este método es aplicable tanto al sensor de NO2 como al de partículas. En este caso la estación almacena el valor mínimo de lectura realizado en los últimos 10 días. Transcurrido este tiempo, la estación toma este mínimo como el nuevo valor cero. Usamos pues el valor mínimo como offset de corrección cada 10 días. La siguiente imagen muestra como el valor mínimo registrado es utilizado para realizar la compensación por nivel cero comentada:

<p align="center">

</p>

La compensación por nivel zero asume que la menor de las lecturas realmente corresponde a la concentración de 0 ug/m3, de forma que antes de habilitar este mecanismo de compensación se hace necesario decidir si la estación es realmente elegible para esta política. Esta técnica es sólo válida allí donde se demuestra que las concentraciones de contaminantes descienden hasta niveles de casi cero en el periodo de 10 días. Estaciones ubicadas en áreas con contínua contaminación y que nunca desciende a niveles de casi cero no deberían apoyarse en este tipo de compensación. En las situaciones de contaminación continuada deberíamos realizar compensaciones manuales basadas en el método del factor-offset.

# Calibración remota

El proyecto RESPIRA incluye la herramienta _RESPIRA tool_, un programa en línea de comando desarrollado en Python para transmitir parámetros de calibración a FIWARE. Toda estación RESPIRA consulta con el Context-Broker FIWARE la existencia de tales parámetros, usándolos antes de posteriores transmisiones (una hora más tarde) para corregir lecturas y activar calibraciones en el propio dispositivo.

El siguiente comando transmite factor de calibración (A) = 1.0021 y offset (B) = -12.687 aplicables a las lecturas de NO2 de la estación con ID RESPIRA_XXXXXXXXXXXX:

```
python3 respira_tool.py --calibrate no2 -d RESPIRA_XXXXXXXXXXXX -f 1.0021 -o -12.687
```

[Esta página](RESPIRA_TOOL.md) explica todo lo necesario sobre la utilidad _RESPIRA tool_ en lo que respecta a la configuración remota de estaciones.

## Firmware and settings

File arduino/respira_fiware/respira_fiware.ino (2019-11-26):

/**
 * Copyright (c) 2019 panStamp <contact@panstamp.com>
 * 
 * This file is part of the RESPIRA project.
 * 
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
 * Author: Daniel Berenguer
 * Creation date: Jul 24 2019
 */

#include <WiFi.h>
#include <esp_system.h>
#include <DNSServer.h>
#include <WebServer.h>
#include <WiFiManager.h>         // https://github.com/tzapu/WiFiManager

#include "config.h"
#include "fiware.h"
#include "respira_sps30.h"
#include "respira_tb600.h"
#include "respira_si7021.h"

#ifdef ENABLE_OTA_PROGRAMMING
#include <ESPmDNS.h>
#include <WiFiUdp.h>
#include <ArduinoOTA.h>
#endif

/**
 * Watchdog
 */
#ifdef WATCHDOG_ENABLED
const uint32_t WATCHDOG_DELAY = 30000000; // in usec
const int loopTimeCtl = 0;
hw_timer_t *timer = NULL;
#endif

// LED pin
#define LED  2

// Wifi managerapp
WiFiManager wifiManager;
const char wmPassword[] = "respira";

// Device MAC address
char deviceMac[16];

// Description string
char deviceId[32];

// FIWARE object
FIWARE fiware(FIWARE_SERVER, FIWARE_UL_PORT, FIWARE_APIKEY, FIWARE_QRY_PORT, FIWARE_SERVICE, FIWARE_SERVICE_PATH, APP_NAME);

// RESPIRA sensor set
RESPIRA_SPS30 sps30;
RESPIRA_TB600 no2Sensor(&Serial2);
RESPIRA_SI7021 si7021;

// Time of last sample in msec
uint32_t lastSampleTime = 0;

// Zero calibration for the NO2 sensor
const uint32_t ZERO_CALIB_LOOPS = ZERO_CALIB_INTERVAL - TX_INTERVAL;
uint16_t zeroCalibLoops = 0;

// Time of last transmission in msec
uint32_t lastTxTime = 0;

// First reading after startup
bool firstReading = true;

// force transmission
bool transmitNow = false;

/**
 * Restart board
 */
void restart(void)
{
  // Restart ESP32
  ESP.restart();  
}

/**
 * readSettings
 * 
 * Read settings received from CB
 * 
 * @param settings Settings received in string format
 * 
 * @return True in case of command successfully processed
 */
bool readSettings(char *settings)
{
  char *ptr1 = settings, *ptr2;
  uint8_t numParam = 0;
  float params[12];

  // Parse config string
  while((ptr2 = strchr(ptr1, '|')) != NULL)
  {
    if (numParam == sizeof(params))
      return false;
      
    ptr2[0] = 0;      
    params[numParam++] = atof(ptr1);
    ptr1 = ptr2 + 1;                
  }

  // Last paramter
  params[numParam++] = atof(ptr1);

  // Check number of parameters and update settings 
  if (numParam == (sizeof(params)/sizeof(float)))
  {
    Serial.println("Updating config settings");
    
    no2Sensor.enableZeroCalib(params[0] > 0);
    no2Sensor.setCalibParams(params[1], params[2]);
    sps30.enableZeroCalib(params[3] > 0);
    sps30.setCalibParams(params[4], params[5], params[6], params[7], params[8], params[9], params[10], params[11]);

    return true;
  }
}

/**
 * transmit
 *
 * Build UL string and transmit to FIWARE IoT agent
 *
 * @return true in case of sucess
 */
bool transmit(void)
{
  char txBuf[256];

  // No2 concentration in μg/m3
  float no2Conc = (float) no2Sensor.getAvgUgM3();
  // CAQI index related to NO2 concentration
  uint16_t caqiNo2 = no2Sensor.getCaqi();
  
  // Temperature in ºC
  float temperature = si7021.getAvgTemperature();
  // Relative humidity
  float humidity = si7021.getAvgHumidity();  

  // Particulate matter
  float pm1 = sps30.getAvgPM1();
  float pm2 = sps30.getAvgPM2();
  float pm4 = sps30.getAvgPM4();
  float pm10 = sps30.getAvgPM10();
  float typSize = sps30.getTypSize();
  // CAQI index related to PM concentration
  uint16_t caqiPm = sps30.getCaqi();

  // Global CAQI index
  uint16_t caqi = caqiPm;
  
  //if (caqiNo2 > caqiPm)
  //  caqi = caqiNo2;

  // Preparing UL frame
  sprintf(txBuf, "t|%.2f|h|%.2f|no2|%.2f|pm1|%.2f|pm2|%.2f|pm4|%.2f|pm10|%.2f|typs|%.2f|q|%d",
    temperature,
    humidity,
    no2Conc,
    pm1,
    pm2,
    pm4,
    pm10,
    typSize,
    caqi
  );  

  Serial.println(txBuf);

  bool ret = fiware.send(deviceId, txBuf); 

  // OK received from server?
  if (ret)
  {   
    // Reset averages
    no2Sensor.resetAvg();
    si7021.resetAvg();
    sps30.resetAvg();
  }

  return ret;
}

/**
 * Main setup function
 */
void setup()
{
  // Let the power supply stabilize
  delay(3000);
  
  // Setup UART
  Serial.begin(115200);
  Serial.println();
  
  // Config LED pin
  pinMode(LED, OUTPUT);
  digitalWrite(LED, LOW);
 
  // Get MAC
  WiFi.begin();
  uint8_t mac[6];
  WiFi.macAddress(mac);
  sprintf(deviceMac, "%02X%02X%02X%02X%02X%02X", mac[0], mac[1], mac[2], mac[3], mac[4], mac[5]);

  // Device ID
  sprintf(deviceId, "%s_%s", APP_NAME, deviceMac);

  Serial.print("Device ID:"); Serial.println(deviceId);
  Serial.print("API Key: "); Serial.println(FIWARE_APIKEY);

  digitalWrite(LED, HIGH);

  // WiFi Manager timeout
  wifiManager.setConfigPortalTimeout(300);

  // WiFi Manager autoconnect
  if (!wifiManager.autoConnect(deviceId))
  {
    Serial.println("failed to connect and hit timeout");
    ESP.restart();
    delay(1000);
  }
  else
  {
    Serial.println("");
    Serial.print("MAC address: ");
    Serial.println(deviceMac);
    Serial.print("IP address: ");
    Serial.println(WiFi.localIP());
  }

  // OTA programming
  #ifdef ENABLE_OTA_PROGRAMMING

  Serial.println("Enabling OTA programming");
  ArduinoOTA.setHostname(deviceId);
  ArduinoOTA.setPasswordHash("39a6fe1d4dac1ead27f12b3c2cbf7221");
  
  ArduinoOTA
    .onStart([]()
    {
      String type;
      if (ArduinoOTA.getCommand() == U_FLASH)
        type = "sketch";
      else // U_SPIFFS
        type = "filesystem";
  
      // NOTE: if updating SPIFFS this would be the place to unmount SPIFFS using SPIFFS.end()
      Serial.println("Start updating " + type);
    })
    .onEnd([]()
    {
      Serial.println("\nEnd");
    })
    .onProgress([](unsigned int progress, unsigned int total)
    {
      Serial.print("Progress: "); Serial.println(progress / (total / 100));
    })
    .onError([](ota_error_t error)
    {
      Serial.print("Error "); Serial.println(error);
      if (error == OTA_AUTH_ERROR) Serial.println("Auth Failed");
      else if (error == OTA_BEGIN_ERROR) Serial.println("Begin Failed");
      else if (error == OTA_CONNECT_ERROR) Serial.println("Connect Failed");
      else if (error == OTA_RECEIVE_ERROR) Serial.println("Receive Failed");
      else if (error == OTA_END_ERROR) Serial.println("End Failed");
    });

  ArduinoOTA.begin();
  
  #endif

  #ifdef WATCHDOG_ENABLED
  Serial.println("Enabling watchdog timer");
  // Watchdog timer
  timer = timerBegin(0, 80, true); //timer 0, div 80
  timerAttachInterrupt(timer, &restart, true);
  timerAlarmWrite(timer, WATCHDOG_DELAY, false); //set time in us
  timerAlarmEnable(timer); //enable interrupt
  #endif
  
  // Initialize sensors
  sps30.begin();
  no2Sensor.begin();
  si7021.begin();

  digitalWrite(LED, LOW);

  lastSampleTime = millis();
}

/**
 * Endless loop
 */
void loop()
{
  if ((millis() - lastSampleTime) >= SAMPLING_INTERVAL)
  {
    digitalWrite(LED, HIGH);
    Serial.println("Reading SPS30");
    if (sps30.read() == RESPIRA_SPS30_OK)
    {
      Serial.println("Reading NO2 sensor");
      if (no2Sensor.read() == RESPIRA_TB600_OK)
      {
        Serial.println("Reading SI7021 sensor");
        si7021.read();
        lastSampleTime = millis();
      }
    }
    digitalWrite(LED, LOW);

    if (firstReading)
    {
      // Force transmission
      firstReading = false;
      transmitNow = true;
    }
  }

  if (((millis() - lastTxTime) >= TX_INTERVAL) || transmitNow)
  {
    digitalWrite(LED, HIGH);

    if (transmitNow)
      transmitNow = false;
   
    Serial.println("Transmitting UL frame");
    if (transmit())
    {
      Serial.println("OK");
      lastTxTime = millis();

      // Zero calibrate?
      if (++zeroCalibLoops == ZERO_CALIB_LOOPS)
      {
        zeroCalibLoops = 0;
        no2Sensor.zeroCalibrate();
      }
    }
    else
      restart();
    

    // Query calibration settings
    char settings[FIWARE_SERVER_RESPONSE_MAXLEN];
    settings[0] = 0;  // Default contents

    Serial.println("Retrieving config settings from FIWARE CB");

    if (fiware.querySettings(settings, deviceId))
      readSettings(settings);
      
    digitalWrite(LED, LOW);

  }
  
  #ifdef WATCHDOG_ENABLED
  // Reset WDT (feed watchdog)
  timerWrite(timer, 0);
  #endif

  #ifdef ENABLE_OTA_PROGRAMMING
  ArduinoOTA.handle();
  #endif
  
  //delay(1000);
}

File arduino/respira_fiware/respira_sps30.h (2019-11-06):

/**
 * Copyright (c) 2019 panStamp <contact@panstamp.com>
 * 
 * This file is part of the RESPIRA project.
 * 
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
 * Author: Daniel Berenguer
 * Creation date: Aug 6 2019
 */

#ifndef _RESPIRA_SENSOR_H
#define _RESPIRA_SENSOR_H

#include "sps30.h"  // Remember to disable INCLUDE_SOFTWARE_SERIAL in sps30.h

#define SP30_COMMS I2C_COMMS

/**
 * Return codes
 */
#define RESPIRA_SPS30_OK               0
#define RESPIRA_SPS30_ERROR_NOREPLY    1
#define RESPIRA_SPS30_ERROR_BADREPLY   2
#define RESPIRA_SPS30_ERROR_NOTFOUND   3
#define RESPIRA_SPS30_ERROR_NOTRESET   4
#define RESPIRA_SPS30_ERROR_NOCLEAN    5
#define RESPIRA_SPS30_ERROR_NOSTART    6

class RESPIRA_SPS30
{
  private:
    /**
     * SPS30 particle sensor object
     */
    SPS30 sps30;

    /**
     * SPS30 structure of values
     */
    struct sps_values sps30Values;

    /**
     * Average concentration of particles
     */
    float avgConcPm1, avgConcPm2, avgConcPm4, avgConcPm10, avgSize;

    /**
     * Number of samples for the calculation of the averages
     */
    uint16_t avgSamples;

    /**
     * Minimum concentration values
     */
    float minPm1, minPm2, minPm4, minPm10;


    /**
     * Zero offset
     */
    float zeroOffsetPm1, zeroOffsetPm2, zeroOffsetPm4, zeroOffsetPm10;
    
    /**
     * Sensor calibration parameters
     */
    float pm1Factor, pm1Offset, pm2Factor, pm2Offset, pm4Factor, pm4Offset, pm10Factor, pm10Offset;
    
    /**
     * Enable zero calibration
     */
    bool enZeroCalib;

  public:
    /**
     * Class constructor
     */
    inline RESPIRA_SPS30(void)
    {
      resetAvg();

      minPm1 = 0;
      minPm2 = 0;
      minPm4 = 0;
      minPm10 = 0;
      
      enZeroCalib = false;
      zeroOffsetPm1 = 0;
      zeroOffsetPm2 = 0;
      zeroOffsetPm4 = 0;
      zeroOffsetPm10 = 0;
      
      pm1Factor = 1;
      pm1Offset = 0;
      pm2Factor = 1;
      pm2Offset = 0;
      pm4Factor = 1;
      pm4Offset = 0;
      pm10Factor = 1;
      pm10Offset = 0;
    }
    
    /**
     * begin
     * 
     * Initialize sensor
     * 
     * @return Return code
     */
    inline uint8_t begin(void)
    {
      uint8_t res = RESPIRA_SPS30_OK;
      
      // set driver debug level
      sps30.EnableDebugging(0);

      // Start communication with SPS30;
      if (sps30.begin(SP30_COMMS) == false)
      {
        Serial.println("could not initialize communication channel.");
        while(1) {}
      }
      
      // Check for SPS30 connection
      if (sps30.probe() == false)
      {
        Serial.println("Could not probe / connect with SPS30.");
        res = RESPIRA_SPS30_ERROR_NOTFOUND;
      }
      else
        Serial.println("Detected SPS30.");

      // reset SPS30 connection
      if (sps30.reset() == false)
      {
        Serial.println("Could not reset SPS30.");
        res = RESPIRA_SPS30_ERROR_NOTRESET;
      }

      uint32_t interval;
      uint8_t ret;
  
      // Get autoclean interval
      if (sps30.GetAutoCleanInt(&interval) == ERR_OK)
      {
        Serial.print("SPS30 : Current Auto Clean interval: ");
        Serial.print(interval);
        Serial.println(" seconds");
      }
      else
      {
        Serial.println("Could not get clean interval.");
        res = RESPIRA_SPS30_ERROR_NOCLEAN;
      }
       
      // Default autoclean interval (~ 1 week)
      interval = 604800;
      if (sps30.SetAutoCleanInt(interval) == ERR_OK)
      {
        Serial.print("SPS30 : Auto Clean interval now set : ");
        Serial.print(interval);
        Serial.println(" seconds");
      }
      else
      {
        Serial.println("SPS30 : Could not set clean interval.");
        res = RESPIRA_SPS30_ERROR_NOCLEAN;
      }
          
      // Start measurement
      if (sps30.start() == true)
        Serial.println("SPS30 : Measurement started");
      else
      {
        Serial.println("SPS30 : Could NOT start measurement from SPS30");
        res = RESPIRA_SPS30_ERROR_NOSTART;
      }

      // Clean now
      if (sps30.clean() == true)
        Serial.println("SPS30 : Fan-cleaning manually started");
      else
      {
        Serial.println("SPS30 : Could NOT manually start fan-cleaning");
        res = RESPIRA_SPS30_ERROR_NOCLEAN;
      }

      return res;
    }

    /*
     * read
     * 
     * Read sensors
     * 
     * @return Return code
     */
    inline uint8_t read(void)
    {
      if (sps30.GetValues(&sps30Values) != ERR_OK)
      {
        Serial.println("SPS30 : Error reading values from SPS30 sensor");
        return RESPIRA_SPS30_ERROR_NOREPLY;
      }

      Serial.print("SPS30 : PM1.0 = "); Serial.print(getMassPM1()); Serial.print(" ug/m3 - ");
      Serial.print("PM2.5 = "); Serial.print(getMassPM2()); Serial.print(" ug/m3 - ");
      Serial.print("PM4.0 = "); Serial.print(getMassPM4()); Serial.print(" ug/m3 - ");
      Serial.print("PM10 = "); Serial.print(getMassPM10()); Serial.print(" ug/m3 - ");
      Serial.print("Avg size  = "); Serial.print(getTypSize()); Serial.println(" um");

      float filtPM1 = getMassPM1();
      float filtPM2 = getMassPM2();
      float filtPM4 = getMassPM4();
      float filtPM10 = getMassPM10();

      // Update minimum concentrations
      if ((minPm1 == 0) || (minPm1 > filtPM1))
        minPm1 = filtPM1;
      if ((minPm2 == 0) || (minPm2 > filtPM2))
        minPm2 = filtPM2;
      if ((minPm4 == 0) || (minPm4 > filtPM4))
        minPm4 = filtPM4;
      if ((minPm10 == 0) || (minPm10 > filtPM10))
        minPm10 = filtPM10;

      // Run factor/offset corrections
      filtPM1 = filtPM1 * pm1Factor + pm1Offset;
      filtPM2 = filtPM2 * pm2Factor + pm2Offset;
      filtPM4 = filtPM4 * pm4Factor + pm4Offset;
      filtPM10 = filtPM10 * pm10Factor + pm10Offset;
      
      // Run zero calibration
      if (enZeroCalib)
      {
        filtPM1 -= zeroOffsetPm1;
        filtPM2 -= zeroOffsetPm2;
        filtPM4 -= zeroOffsetPm4;
        filtPM10 -= zeroOffsetPm10;
      }

      // Update averages
      avgConcPm1 += filtPM1;
      avgConcPm2 += filtPM2;
      avgConcPm4 += filtPM4;
      avgConcPm10 += filtPM10;     
      avgSize += getTypSize();
      avgSamples++;

      return RESPIRA_SPS30_OK;
    }
        
    /*
     * getMassPM1
     * 
     * Get mass concentration of the PM1.0 particles from SPS30 sensor
     * 
     * @return mass concentration of the PM1.0 particles in μg/m3
     */
    inline float getMassPM1(void)
    {
      return sps30Values.MassPM1;
    }

    /*
     * getMassPM2
     * 
     * Get mass concentration of the PM2.5 particles from SPS30 sensor
     * 
     * @return mass concentration of the PM2.5 particles in μg/m3
     */
    inline float getMassPM2(void)
    {
      return sps30Values.MassPM2;
    }

    /*
     * getMassPM4
     * 
     * Get mass concentration of the PM4.0 particles from SPS30 sensor
     * 
     * @return mass concentration of the PM4.0 particles in μg/m3
     */
    inline float getMassPM4(void)
    {
      return sps30Values.MassPM4;
    }
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

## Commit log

2019-08-19 Updating connectors and main SoC
    [respira_fiware.sch]
2019-09-02 Removing AC parts
    [respira_fiware.kicad_pcb, respira_fiware.sch]
2019-09-02 New auxiliary sensor board
    [sensor_board.kicad_pcb, sensor_board.sch]
2019-09-02 New image of ESP32 module
2019-09-02 D1 removed
    [respira_fiware.kicad_pcb, respira_fiware.sch]
2019-09-05 Minor arrangements
    [respira_fiware.kicad_pcb, respira_fiware.sch]
2019-09-05 New class for the SPS30 sensor
2019-09-05 New class for the NO2 sensor
2019-09-09 Moving each sensor to a different class
2019-09-09 Preparing for production
    [respira_fiware.kicad_pcb]
2019-09-09 Fixing format for example of UL frame
2019-09-17 Debug printouts
2019-09-17 Addition of EC1-NO2-50 sensor
2019-09-19 LED flashes when reading sensors
2019-09-19 Removing special characters from printouts
2019-10-01 Printing API key
2019-10-05 Preparing for remote calibration
2019-10-07 Reformatting UL frame to force a single NGSI query
2019-10-07 Fixing NGSI entity query
    [respira_fiware.ino]
2019-10-09 Adding calibration instructions
2019-10-09 Fixing zero-calibration
2019-10-17 Production files
    [respira_fiware-B.Mask.gbr, respira_fiware-B.SilkS.gbr, respira_fiware-Back.gbr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]
2019-10-17 Working flow diagram
2019-10-25 Adding reference to ArduinoOTA library
2019-11-06 Print serial frame received from TB600 board
2019-11-20 Restart in case of negative or lack of response from server
2019-11-24 New sample code for ESP8266 and the SI7021 dual temperature and humidity sensor

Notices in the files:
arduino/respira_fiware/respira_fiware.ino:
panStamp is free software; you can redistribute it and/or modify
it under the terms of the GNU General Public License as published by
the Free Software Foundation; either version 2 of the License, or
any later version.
